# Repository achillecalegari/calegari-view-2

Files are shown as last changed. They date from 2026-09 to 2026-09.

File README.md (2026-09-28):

# Calegari View 2

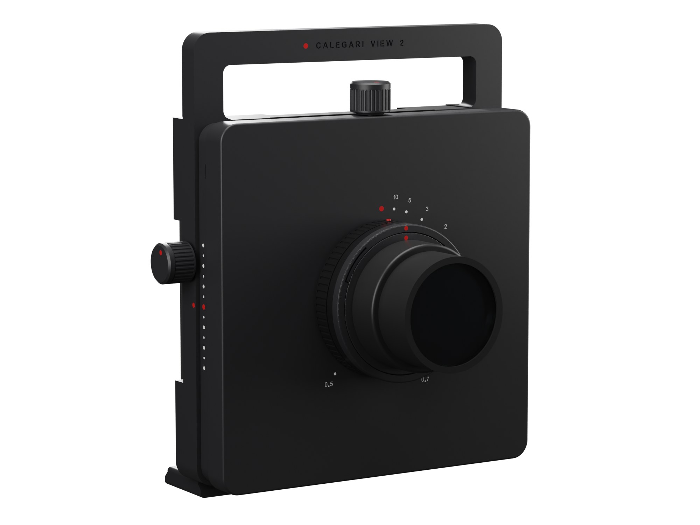
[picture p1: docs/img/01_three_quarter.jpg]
Calegari View 2


A rigid 6x7 view camera for architecture that you print at home and put together without a single screw. No inserts, nuts, springs, bushings or grub screws: the printed parts slide in dovetails, snap together and press in. The rise is a self-locking printed worm turned from a knob on the side through a printed miter pair, the shift knob rides on the lens panel, and the back turns from landscape to portrait with a click. Only the focusing helicoid and a sheet of velvet are bought, then the lens and the film back.

**[Project page](https://achillecalegari.github.io/calegari-view-2/)** · [Shopping list](docs/bom.md) · [Test prints](docs/test-prints.md) · [Printing](docs/printing.md) · [Assembly](docs/assembly.md) · [Calibration](docs/calibration.md) · [Using the camera](docs/using.md) · [Design notes](docs/design.md)

## Why

[Calegari View 1](https://github.com/achillecalegari/calegari-view-1) works, but building it means buying and sorting screws, inserts and nuts in half a dozen sizes. View 2 asks what a printer can do by itself. Every fastener of View 1 has a printed answer here: dovetail ways with a flexure beam instead of a gib, a self-locking worm and a rack and pinion instead of lead screws, knobs that snap onto their shafts, plugs that close the ways, a bayonet for the lens boards. It also moves further (30 mm each way instead of 25), the film turns instead of the camera, and it looks like one object: at zero the three plates are a single square block.

## What it is

| | |
|---|---|
| Format | 6x7 (56 x 69.5 mm), Mamiya RB67 Pro, Pro-S, Pro-SD backs on a Graflok-type seat (View 1's) |
| Lens | 65 mm large-format wide angle in Copal 0 (Super-Angulon, Nikkor-SW, Grandagon-N) on a 70 mm round board, one per lens |
| Movements | rise and fall 30 mm on a self-locking worm, pi mm per turn: it stays where you leave it, whatever the lens weighs; shift 30 mm each way on a rack and pinion, 37.7 mm per turn; a click at zero, hard stops at the ends |
| Back | turns 90 degrees on a round rotator, a click and a stop at landscape and at portrait; the camera stays level on the tripod |
| Clean corners | 30 mm on one axis, 25 + 25 mm combined at infinity, in both orientations; the lens's image circle is the limit, not the camera |
| Focus | M65 helicoid 17 to 31 mm, turned by its own grip; engraved distance scale from infinity to 0.5 m |
| Lens change | a three-lug bayonet, a 40 degree turn and a click; the shutter always ends upright |
| Tripod | the foot is an Arca-Swiss dovetail across the whole width, printed with the body |
| Handle | full width, posts and bar the same 16 mm, engraved name; the shift knob centred in its window |
| Light seal | self-adhesive velvet between the sliding plates, at least 6.1 mm wide at every position; a ring labyrinth behind the rotator |
| Size | 180 x 222 mm front (197 mm wide with the rise knob), 161 mm deep with back and lens |
| Weight | about 1 kg without back and lens, helicoid included (estimate from the model) |
| Bought | the helicoid and a sheet of velvet: 40 to 70 EUR, plus ASA and a little TPU |

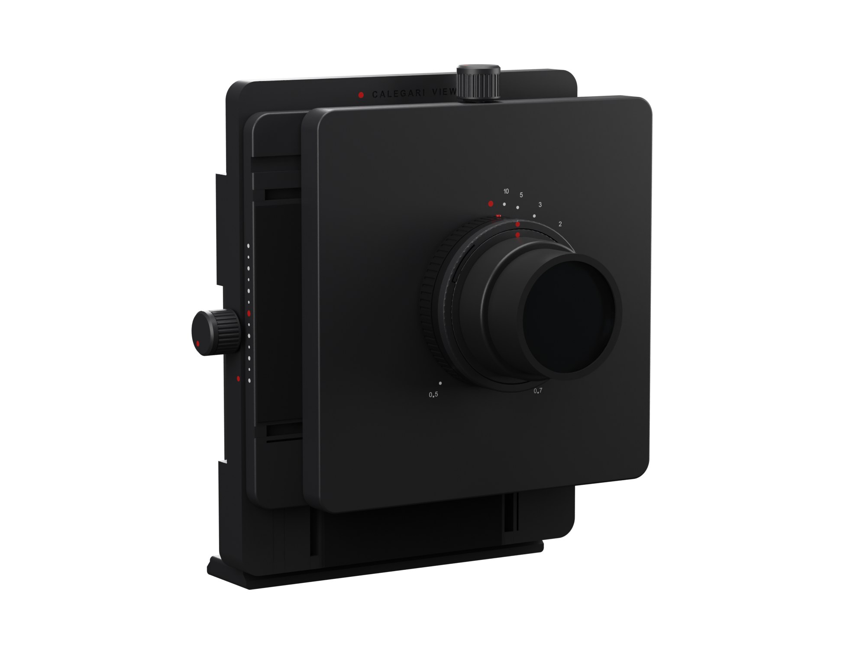
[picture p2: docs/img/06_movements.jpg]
Rise and shift


## How it works

| Function | How |
|---|---|
| Body | one print: body, full-width handle, the Arca foot, the rotator's recess with its lugs and springs |
| Ways | printed 60 degree dovetails; one groove of each pair has a flexure beam for a wall, which preloads the plate: no gib, no grubs, and it takes up wear by itself |
| Rise | a printed worm hidden in the body's right side; its rack is moulded into the Y plate as the exact negative of the worm. A 7 degree lead against a 17 degree friction angle: self-locking. A printed miter pair turns it from the knob in the middle of the right side face |
| Shift | module 1 rack and 12-tooth pinion, teeth printed in the bed plane; the pinion lives in the lens panel, its knob on the panel's top edge, so it rides with the lens |
| Knobs | knurled, snap onto a D-shaped shaft; a TPU wave washer under each gives an even drag |
| Zero clicks | a flat spring cut into the moving plate's back, with a bump that drops into a dimple |
| Stops | the grooves are closed at one end; a printed plug pressed into the other end after assembly |
| Focusing | the helicoid screws into an M65 thread printed in the lens panel. Infinity sits 0.3 mm short of its closed stop, like any lens |
| Lens mount | a ring flush with the helicoid, so helicoid and mount read as one barrel; the board's plateau is printed to the lens's flange focal distance |
| Back | View 1's Graflok seat on a round rotator: two lugs, three printed springs, a stop peg; a red blade in dovetail rails, clamped by a printed wheel on a printed M6 stud |

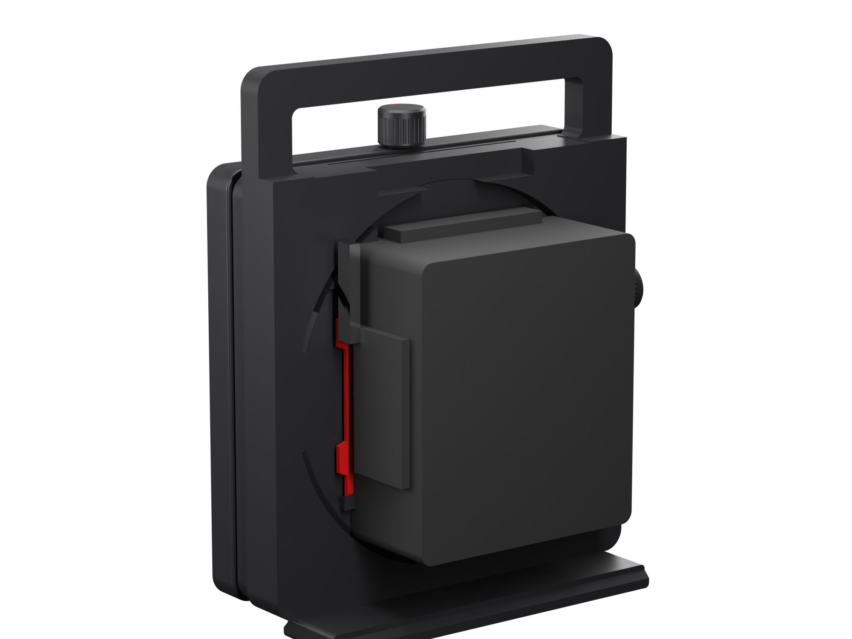
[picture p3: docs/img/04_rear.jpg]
From behind


## Checked before it is printed

- `cad/check.py`: every pair of parts at eleven positions: zero, the four corners of the travel, two single-axis ends, blade open, the back in portrait and half way round. Designed contacts (flexure preload, detent bumps, pressed rack, plugs and peg, squeezed washers) each have a volume budget; everything else must not touch. **0 problems.**
- `cad/fitcheck.py`: the mechanisms: the worm against its rack over the whole travel, the miter pair over a tooth pitch, every part going in and in order, the plugs and the collar, the rotator going in only at its angle, held on its lugs, stopped at both ends; the bayonet, the pinion, the knobs' snap, the Graflok blade, the dovetails, the test rigs. **62 checks, all pass.**
- `cad/seal_check.py`: the velvet band between the sliding plates, swept every 5 mm. **6.15 mm at the narrowest.**
- `cad/optics_check.py`: rays from the lens to the four corners of the film through every part, at infinity and focused close, landscape and portrait. **Clean at 30 mm on one axis and 25 + 25 combined at infinity; 22 + 22 at about 0.9 m.**

## Print, then build

1. [Test prints](docs/test-prints.md): four small plates that prove the thread, the bayonet, the drive and the dovetails on your printer.
2. [Printing](docs/printing.md): seven plates.
3. [Assembly](docs/assembly.md): eleven steps in 22 illustrated sub-steps, no tools but scissors and a craft knife for the velvet.
4. [Calibration](docs/calibration.md): the light test, infinity, other lenses, the feel of the movements.

Everything is generated with Python and [build123d](https://github.com/gumyr/build123d) from `cad/params.py`: change a number, run `python export.py`, print.

## Licence

[CC BY-NC-SA 4.0](LICENSE): build it, change it, share it with credit; do not sell it. The RB67 interface comes from View 1, measured from [Super-67](https://github.com/DamienHazard/Super-67) and the [RB67 pinhole body](https://www.thingiverse.com/thing:7270507).

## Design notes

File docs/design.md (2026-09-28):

# Design notes

[Back to the project](../README.md)

View 2 asks one question of [View 1](https://github.com/achillecalegari/calegari-view-1): which of its sixty-odd bought fasteners can a printer replace, and how, without the camera getting worse? All of them, it turned out. Then two more: can it look like one object instead of a stack of parts, and can the film turn instead of the camera?

## What replaced what

| View 1 | View 2 | How it prints |
|---|---|---|
| Printed rails screwed on with M2.5 and M3 into inserts | grooves cut into the body and the Y plate, tongues printed on the moving plates | grooves open on the bed, tongues on top, 30 degree flanks |
| Gib strip and three grub screws per way | one groove's outer wall is a flexure beam, 1.2 mm thick and 7 mm tall, 0.25 mm interference | the slit prints open on the bed; the beam bends across the layers |
| M6 lead screw, brass nut, bushings, cap nut (rise) | a printed worm, 8 mm pitch diameter, and a rack moulded into the Y plate, cut as the negative of the worm; a printed miter pair turns it from the side knob | the worm and the knob's gear stand up; the rack's layers each hold the worm's tooth profile |
| M6 lead screw and nut (shift) | module 1 rack and 12-tooth pinion, 37.7 mm per turn | teeth in the bed plane: exact involutes; the rack prints lying on its side |
| O-ring under the knob | a TPU wave washer under each knob: a 0.8 mm ring on three feet each side, squeezed 0.3 mm | flat |
| Ball plunger and dimple | a flat spring cut into the moving plate's back, with a bump near its free end, and a dimple in the other plate | the spring prints flat over a cavity |
| Knobs with a stud, a nut and a grub screw | knurled knobs that snap onto D shafts: two tabs drop into a groove | crown down; the tabs bend in the bed plane |
| Hard stops at the ends of the screw channels | closed groove ends, and a plug pressed into the open end after assembly | |
| RafCamera metal flange, four screws | an M65 x 1 thread printed in the lens panel | 0.12 mm layers, thread axis vertical |
| Focus ring with four grub screws and a hidden stop | the helicoid's own grip; a scale engraved on the panel, an index painted on the grip | |
| Technika board, holder, latch, spring, screws, inserts | a 70 mm round board on a three-lug bayonet with a flexure detent | the lugs' undersides are chamfered: no overhang |
| Brass shims for other lenses | the board's plateau is printed for each lens's flange focal distance | `python board.py 71.2` |
| Graflok module, four screws, four inserts; an L bracket for portrait | a round rotator that carries the Graflok seat and turns the back 90 degrees, held by two lugs and three printed springs | front face down; the lugs are 45 degree cones, no overhang |
| Graflok wheel on an M3 screw | a printed wheel on a printed M6 stud | stud printed standing |
| Two aluminium Arca plates, screws, inserts | the foot is an Arca dovetail, printed with the body | 45 degree flanks |
| Top handle, screws, inserts, levels | printed with the body, full width | |

What stayed bought: the helicoid, a precision thread that must not wobble or tilt the lens, and it costs less than the test prints of a printed one; and the velvet. TPU lip seals were drawn and dropped: no single lip stays on solid faces on both sides while two plates slide in two directions. The velvet seals by area, as on View 1.

## Why the front standard stays up

The front standard (Y plate, lens panel, helicoid and a 65 mm lens in its shutter) weighs about 0.8 kg: 8 N on the rise drive. The first View 2 raised it with a rack and a 12-tooth pinion, like the shift. A spur pinion runs backwards as easily as forwards: 8 N at its 6 mm pitch radius is 0.05 N·m trying to turn the knob, and nothing but the friction of the ways was holding it. With a light coat of PTFE, which the guide recommended, the front would have crept down on its own.

The rise is now a worm. One turn of the knob moves the plate one lead, pi mm, and the lead climbs the 8 mm worm at 7.1 degrees. A load on the rack pushes along the worm's axis, and it can only turn the worm if the flank's slope beats the friction on it: dry ASA on ASA has a friction angle of about 17 degrees, far above 7.1. The worm cannot be turned by its load, at any position, with any lens. PTFE would bring the friction angle near the lead angle, so the worm and its rack stay dry; the shift, which gravity does not pull while the camera is level, keeps its fast rack and pinion.

The rack is the other half of the trick. A straight-toothed rack only matches a worm in the plane through its axis; a millimetre to either side the worm's flank has moved and the teeth collide (the first prototype did, by 3 to 9 mm³). But a worm that turns is the same surface as a worm that slides along its axis, so the rack that meshes with it over its whole face is simply the negative of the worm: a slice of a nut, cut by a worm 0.15 mm fatter than the real one. In each printed layer of the Y plate the rack's section is the worm's own tooth profile. `fitcheck.py` turns the worm through the whole travel against it: 0.003 mm³ of contact, numerical noise.

The worm stands inside the body's right side and nothing of it shows. Its top carries a small straight bevel gear; a second one, on a shaft through the side face, meets it at right angles: a miter pair, 12 teeth, module 0.75, one to one. The knob sits on that shaft; turned clockwise, it raises the front standard. Both gears stay inside the worm's own envelope, 10.2 mm across, so the body stays 22 mm deep around them. Their teeth end on the back cone, as on a real bevel gear: the core behind each heel stays inside the other gear's reach, and every slope is 45 degrees or steeper, so both print standing without support. A collar pressed into the side bore under the knob holds the knob's gear in; the pin at the worm's bottom stands in a plug pressed into the bore from below, and that seat is the thrust bearing. A small stub on the knob's gear, just above the worm's top, stops the worm lifting.

The knob sits in the middle of the side face, the body and the handle's post together. It cannot come lower: the gear sits above the worm, the worm above the rack's highest point, and the rack's channel has to stay behind the Y plate at every rise and fall, so the rack has only three teeth and starts as low as that allows.

## The back turns, the camera does not

View 1 needed an L bracket and a second Arca plate for portrait, and a camera on its side is awkward to use. View 2 turns the film instead. The Graflok seat, its rails, blade and wheel are one round plate, the rotator, 160 mm across, in a round recess in the body's back.

- **Held:** two lugs at the recess rim, 45 degree cones on the underside, over a matching bevel on the rotator's back edge. Three flat springs cut into the recess floor push the rotator back onto them. The cone contact centres it and sets its plane; the film plane is the rotator's seat, and the ground glass and the film sit on the same seat, so focus stays true in both positions.
- **Clicks:** each spring's bump drops into a shallow dimple at landscape and at portrait. The dimples are 0.25 mm deep against a 0.4 mm bump, so the springs keep part of their preload at rest: the rotator never floats.
- **Stops:** a peg pressed through the body's left side face runs in a 90 degree groove on the rotator's rim.
- **Goes in:** the rotator has two notches in its rim. Turned 135 degrees, and only there, they pass the lugs. The working range, 0 to -90, never reaches that angle, and the peg, pressed in last, makes sure of it.
- **Dark:** the rotator's front face meets the recess floor across a ring rib that sits in a groove: light coming round the rim has to turn twice. The openings in front are square, so the frame fits in both orientations; that is one reason the block grew from 162 mm.
- **The dark slide:** it comes out on the photographer's right in landscape and at the top in portrait. The body is notched for it on both sides, and the handle stands 2 mm off the back so the slide's grip passes under it.

The springs sit at 15, 135 and 255 degrees. Three springs 120 degrees apart never meet each other's dimples inside the working range, so the back clicks only at its two positions; and none of the six dimples falls in the dark-slide relief, where the rotator is thin.

## One block

At zero the body, the Y plate and the lens panel are one square, 180 mm, with the Y plate 1.5 mm smaller all round: from the side the three layers read as a single block with two shadow lines. The body and the handle share one front face, printed in one piece, with the same 9 mm corner at the top of the handle and at the bottom of the body; seen from the front the handle's posts and its bar are the same 16 mm. The front of the camera is the lens panel and the barrel, nothing else: the helicoid's grip and the lens mount are the same diameter, so they read as one barrel, and the distance scale is engraved around it. There are two controls, two knurled knobs as on View 1: the shift knob stands on the lens panel's top edge, centred in the handle's window, and rides with the lens; the rise knob stands in the middle of the right side face.

Without the side leg the camera sits on the tripod one way, and it needs no plinth: the foot is simply an Arca-Swiss dovetail across the whole width, 9.5 mm tall, centred 32 mm behind the body's front face under the rotator. At full fall the plates drop past it in front of the clamp.

## Why 30 mm and not 40

With sliding plates, the light seal is geometry. The middle plate must stay covered by the plate behind it at the end of its travel, and its own window has to be wider than the light cone by the other plate's travel. Each millimetre of travel costs about 3.2 mm of camera. At 30 mm each way the light needs 170 mm; the block is 180, and the extra 5 mm a side is where the rise's miter pair lives. At 40 mm it would be over 200 and the body would no longer print in one piece on a 256 mm bed. And a 65 mm lens with a 160 mm image circle covers 30 mm on one axis anyway, 25 + 25 combined: past that, a bigger camera buys nothing.

## Focusing and infinity

The helicoid is closed at 17 mm; infinity is at 17.3. That is 0.3 mm, about 7 degrees of the grip, of travel past infinity, which every lens has and which makes infinity easy to find by feel. The lens panel's front sits at 70.5 - 5 - 17.3 = 48.2 mm from the film, the mount is 5 mm long, the board's front is at the lens's flange focal distance. Changing lens changes only the board.

## Findings along the way

- **The helicoid's rear tube limits combined shifts.** Its bore (61 mm) sits 5.5 mm deep in the lens panel. At infinity the corners stay clean to 25 + 25 mm; focused at about 0.9 m the lens moves out, the corner rays open up and the tube clips them past 22 + 22 mm. View 1's ray trace did not model the tube.
- **A detent bump must sit near the spring's free end.** Near the root, a 1.4 mm ASA spring deflected 0.4 mm would see several times its yield stress; near the free end, 12 MPa and a light 2 N click. The bump also has to reach across the gap, or it never clicks.
- **A solid TPU washer is a brick.** Squeezed 0.3 mm over its whole face it would push with hundreds of newtons. The wave washer bends between its feet: a few newtons, an even drag.
- **Press fits need interference.** The plugs, the rack and the stop peg are drawn 0.1 mm larger than their slots; with zero they would fall out.
- **A part has to be able to go in, and in the right order.** The worm's gear is wider than the rack lets through, so the worm goes up its bore before the Y plate, and its plug is notched where the rack's channel crosses the bore: the rack slides up past it and threads onto the worm from below. A second plug closes the channel afterwards. `fitcheck.py` checks every path.
- **A long press fit is a stuck part.** A plug pressed over 25 mm would need a vice. The long plugs press only over a 6 mm band at the bottom and slide above it.
- **A slot must stay inside its part.** With View 1's M3 screw the Graflok blade's slot was small; with a printed M8 stud it grew until it broke 0.2 mm through the blade's top edge, a hairline split. The stud is now M6 and 1 mm lower: 1.9 mm of blade above the slot, 3 mm below, checked in `fitcheck.py`.
- **A name prefix can hide a part.** An early ray trace skipped everything whose name began with "lens", including the lens panel. The panel is in the trace now.

## Checks

`check.py` (every pair of parts at eleven positions, landscape, portrait and half way; designed contacts on a volume budget), `fitcheck.py` (the mechanisms: worm and rack over the whole travel, the rotator going in, held and stopped, the miter pair, the parts going in, the bayonet, the pinion, the knobs, the Graflok blade, the dovetails), `seal_check.py` (the velvet band), `optics_check.py` (ray trace through every part, at infinity and focused close, in both orientations).

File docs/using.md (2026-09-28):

# Using the camera

[Back to the project](../README.md)

## From the bag to the negative

1. **Tripod.** Clamp the foot: it is an Arca-Swiss dovetail across the whole width. The camera goes on one way only; for portrait you turn the back, not the camera. Level it with the tripod head's level or a spirit level laid on the handle. For architecture the camera stays level; the movements do the framing.
2. **Landscape or portrait.** Grip the back and turn it a quarter turn until it clicks.
3. **Zero.** Turn both knobs until they click: the red dots on the side and on top line up with the red indexes. The lens is centred on the film.
4. **Compose.** Ground glass on, shutter open at full aperture, dark cloth. The rise knob is in the middle of the right side: clockwise, as you face it, raises the lens, 3.14 mm per turn; the lens stays exactly where you leave it, whatever it weighs. The shift knob stands on the lens panel's top edge and travels with it, 37.7 mm per turn. The dots are every 5 mm, the bigger ones every 10.
5. **Focus.** Turn the helicoid's grip, with a loupe on the ground glass. The index on the grip reads the distance on the scale engraved around it.
6. **Close the shutter**, set the aperture and speed, cock it.
7. **Swap the ground glass for the film back** (Graflok: wheel loose, blade down, back on, blade up, wheel tight). Pull the dark slide, shoot, slide back in.

## What the movements are for

- **Rise.** The camera stays level, so verticals stay vertical; the lens goes up until the top of the building is in the frame. With a 65 mm lens, 30 mm of rise lifts the top edge of the frame from 23 to 42 degrees above the horizon.
- **Fall.** The same, downward: a table, a floor, a view from a balcony.
- **Shift.** Sideways: a facade straight on while standing to one side of it, or a mirror or a window without your own reflection.
- **Together.** Up to 25 + 25 mm at infinity. Check the corners on the ground glass at the taking aperture: with a 160 mm image circle that is its edge.

## Changing the lens

Turn the board firmly anticlockwise (seen from the front) until it stops, about 40 degrees, and lift it out. The next board goes in turned the same way, pushed flat, then clockwise until it clicks: red dots together, shutter upright. Ten seconds, no tools. Every board is printed for its own lens, so infinity stays where it was.

## Care

- A light coat of dry PTFE on the dovetails and the shift rack once a year. Never on the rise worm or its rack: they must stay dry to lock. No oil or grease anywhere on the ASA.
- Keep it out of a hot car: ASA is fine to about 90 C, the velvet's glue is not.
- If a plate gets stiff after months, the flexure takes up the wear by itself; stiff means dirt: slide the plate out (pull the two plugs with a pin; for the Y plate, pull the rack plug too and turn the rise knob anticlockwise to run the rack down off the worm), wipe, back in.

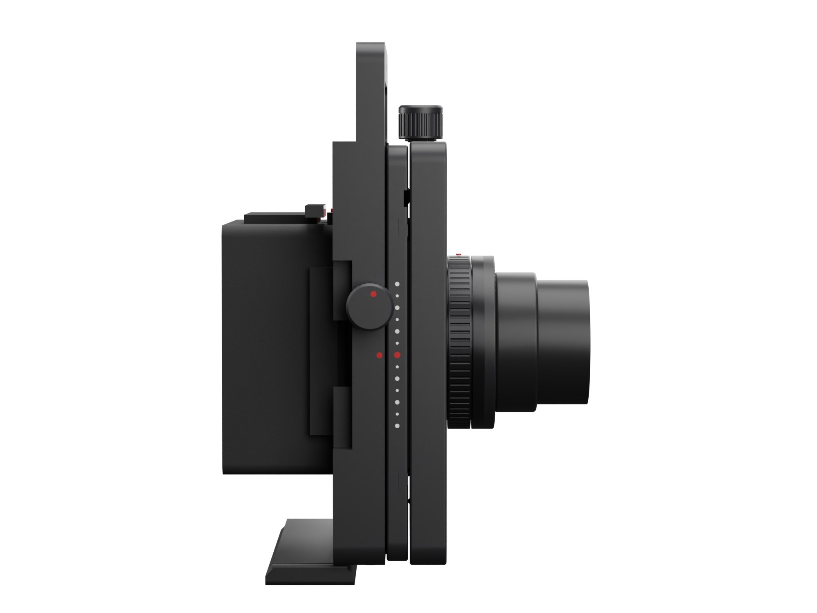
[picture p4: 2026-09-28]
docs/img/03_side.jpg

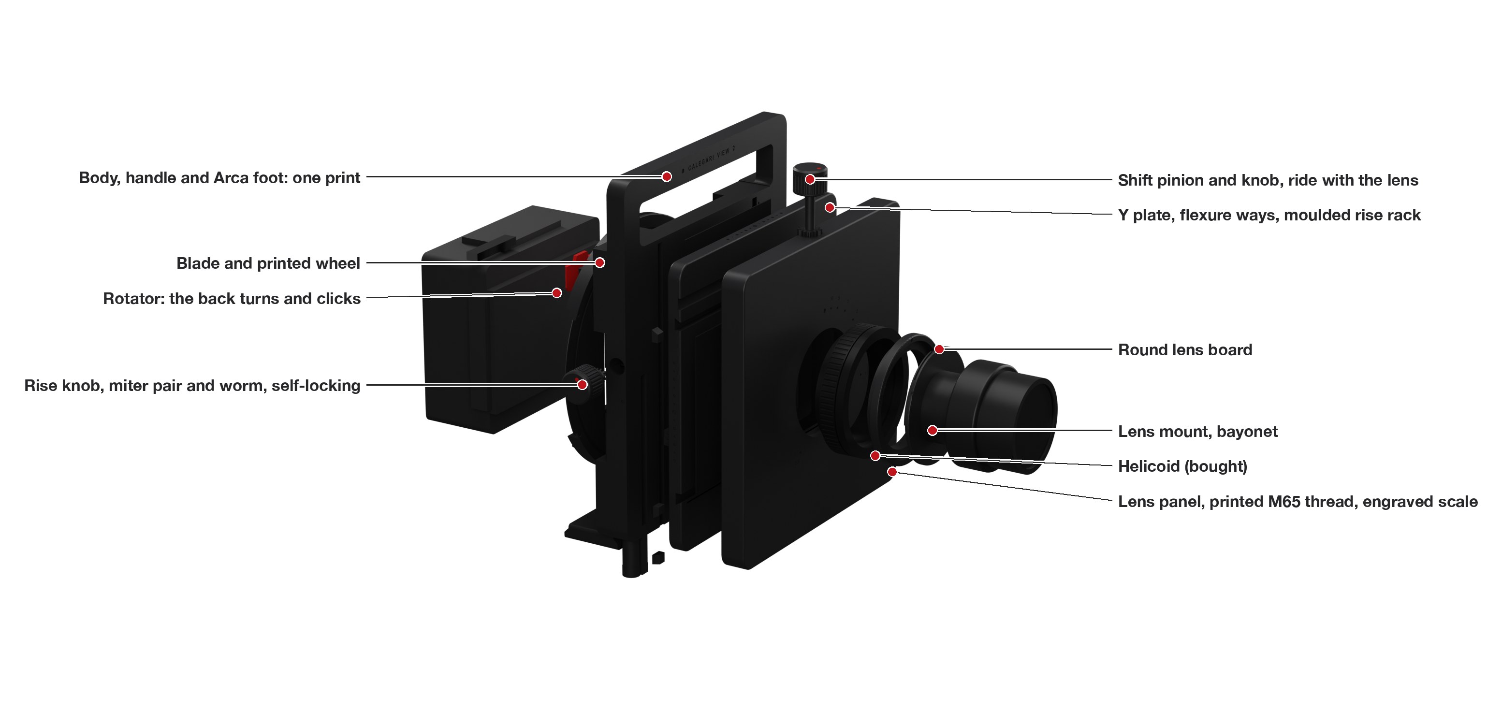
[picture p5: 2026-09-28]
docs/img/07_exploded.jpg

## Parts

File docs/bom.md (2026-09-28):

# Shopping list

[Back to the project](../README.md)

## The camera

| Item | Spec | Qty | Where | About |
|---|---|---|---|---|
| Focusing helicoid | M65 x 1 to M65 x 1, 17 to 31 mm; the front must not rotate | 1 | [AliExpress](https://it.aliexpress.com/item/1005007466119142.html) (option "m65-m65 17-31") or [RafCamera](https://raf.camera/products/m65x1-focusing-helicoid-with-17-31mm-extension-range) | 30 to 60 EUR |
| Velvet | black, self-adhesive, 0.9 to 1.2 mm thick, one A4 sheet is plenty | 1 | [Amazon.it](https://www.amazon.it/dp/B005FWUK44) | 10 EUR |
| ASA | black, about 900 g (a 1 kg spool); red, a few grams for the Graflok blade | 1 kg + a little | [Bambu Lab](https://eu.store.bambulab.com/products/asa-filament) | 30 EUR |
| TPU 95A | black, two grams for the two wave washers | a little | any | |
| Acrylic paint | red and white, a toothpick: the dots and the numbers are engraved to be filled | 1 each | any art shop | |
| Dry PTFE spray | optional: one light coat on the dovetails and the shift rack, never on the rise worm | 1 | any hardware shop | |

That is all. No screws, inserts, nuts, springs, bushings, grub screws, levels or Arca plates.

## To shoot with it

| Item | Spec | Where |
|---|---|---|
| Lens | 65 mm large-format wide angle in a Copal 0 shutter: Schneider Super-Angulon 65/8 or 65/5.6, Nikon Nikkor-SW 65/4, Rodenstock Grandagon-N 65/4.5. An image circle of 160 mm or more covers the full movements | used |
| Film back | Mamiya RB67 Pro, Pro-S or Pro-SD, 120 | used |
| Ground glass | a Graflok 23 ground glass back (Mercury Works makes new ones), or a used one | new or used |
| Cable release | any, for the shutter | |
| Dark cloth, 4x loupe | for the ground glass | |

Every lens gets its own printed board: [calibration](calibration.md) tells how to print one for a lens other than the Super-Angulon 65/8.

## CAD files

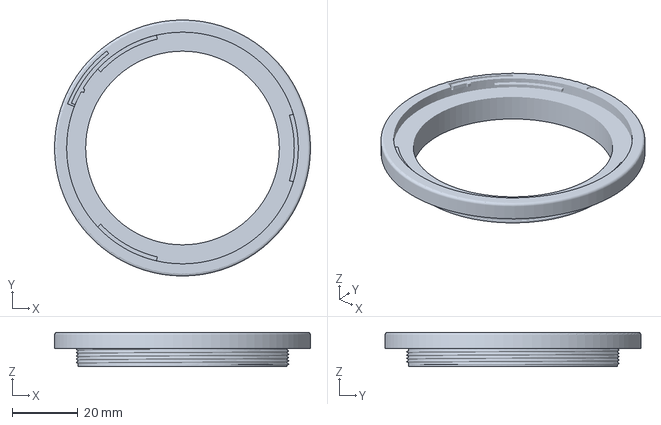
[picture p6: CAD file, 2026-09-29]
print/plates/plate_05_black_0.12mm_layers.3mf
78.0 x 78.0 x 10.5 mm

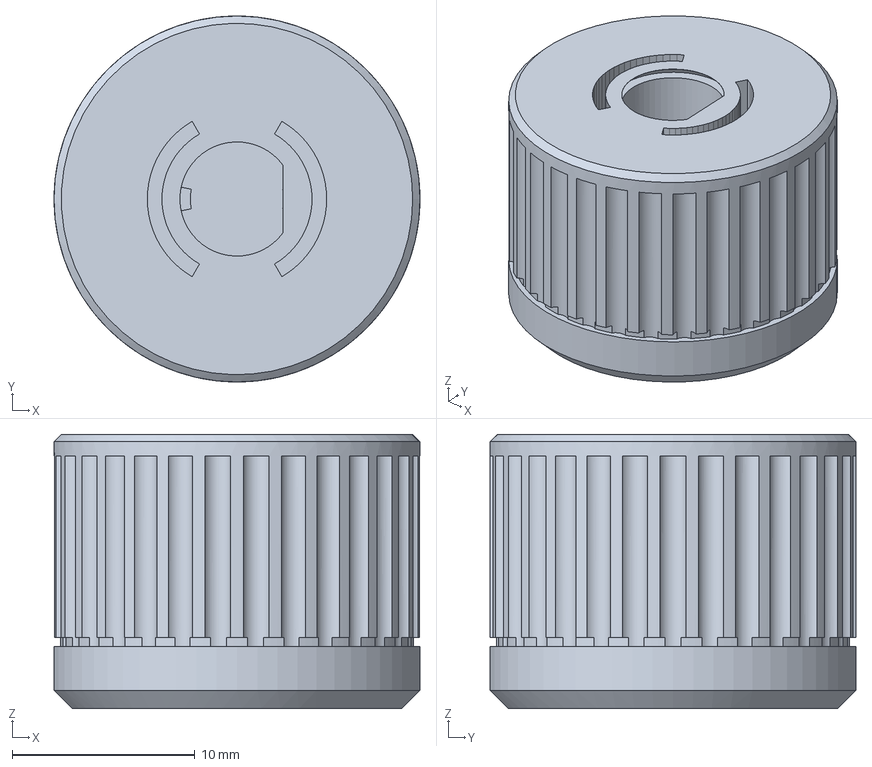
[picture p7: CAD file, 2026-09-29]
print/step/knob.step
20.0 x 20.0 x 15.0 mm

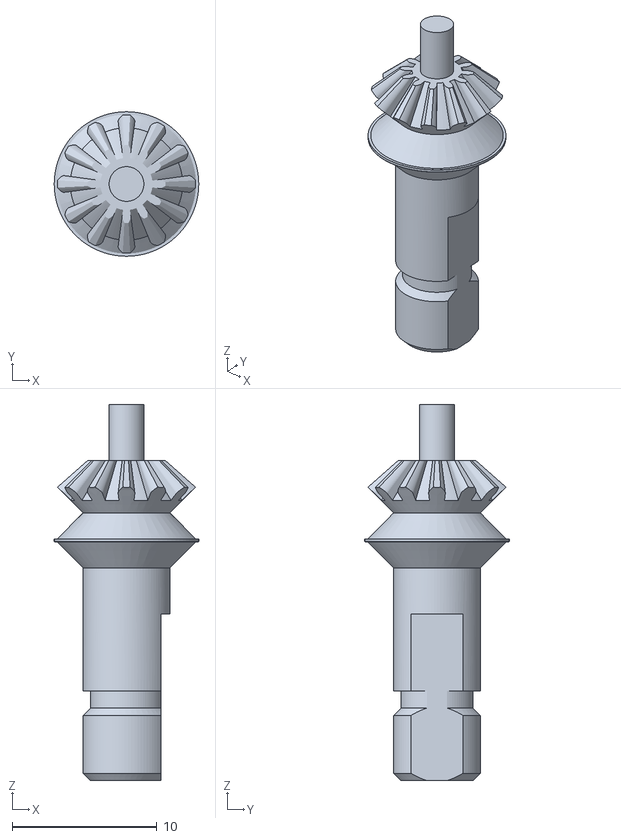
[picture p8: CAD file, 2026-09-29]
print/test/knob_gear.stl
10.0 x 10.0 x 26.0

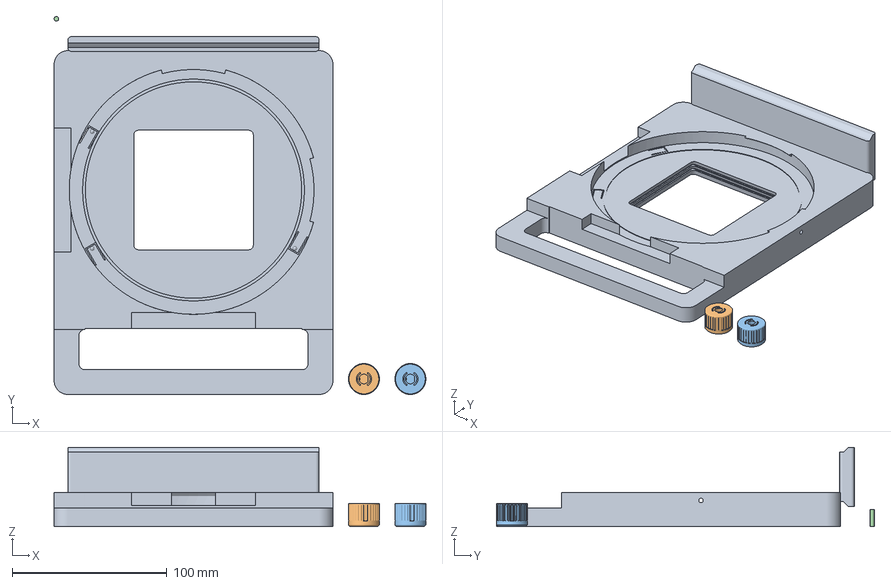
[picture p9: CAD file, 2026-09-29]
print/plates/plate_01_black.3mf
240.0 x 244.0 x 51.0 mm
knob_1
knob_2
stop_peg

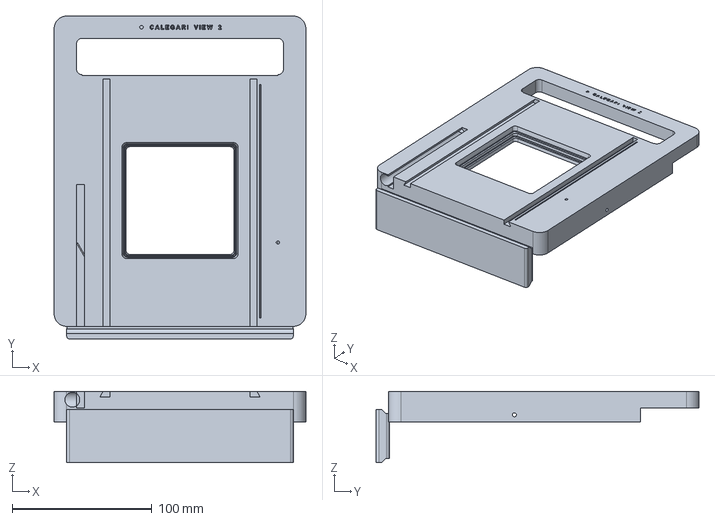
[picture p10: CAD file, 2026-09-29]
print/step/body.step
180.0 x 231.0 x 51.0 mm

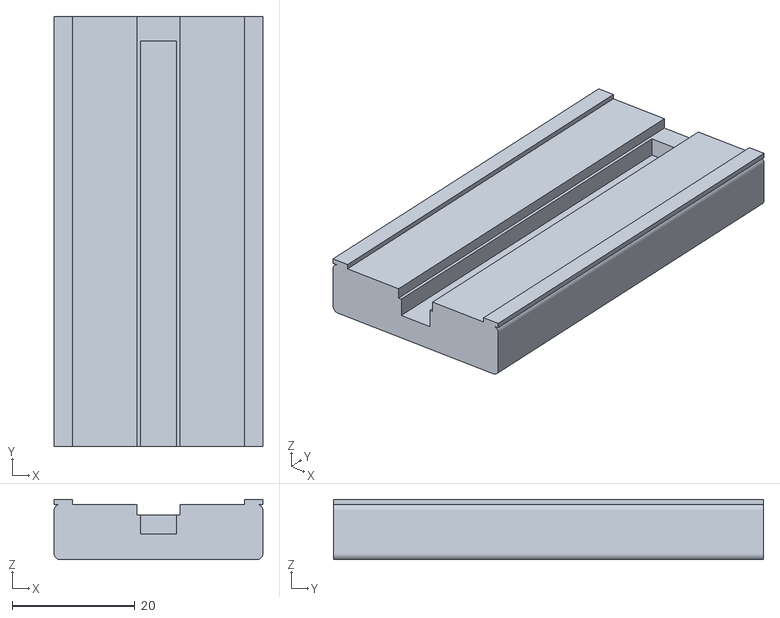
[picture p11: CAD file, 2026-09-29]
print/test/rack_carrier.stl
34.0 x 70.0 x 9.80

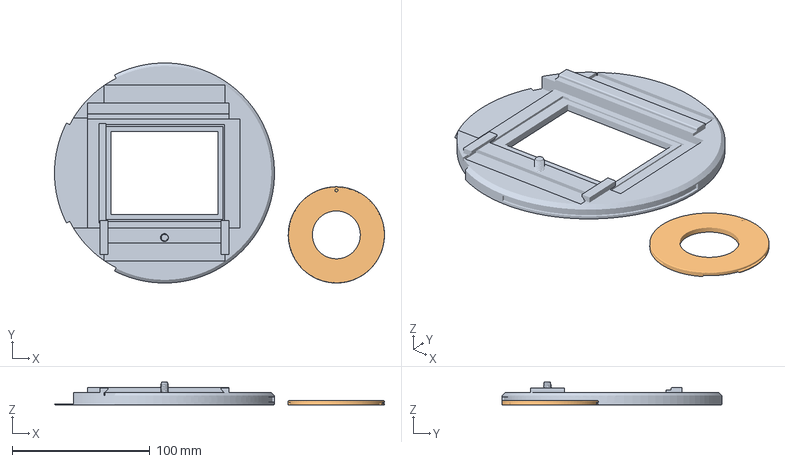
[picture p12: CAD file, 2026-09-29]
print/plates/plate_03_black.3mf
239.9 x 160.0 x 16.4 mm
rotator
lens_board

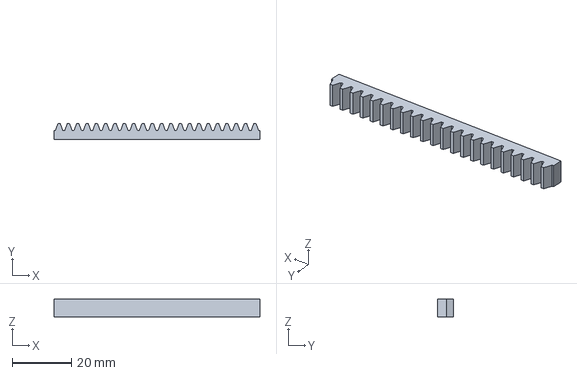
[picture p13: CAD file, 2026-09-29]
print/step/rack_shift.step
69.4 x 5.25 x 6.00 mm

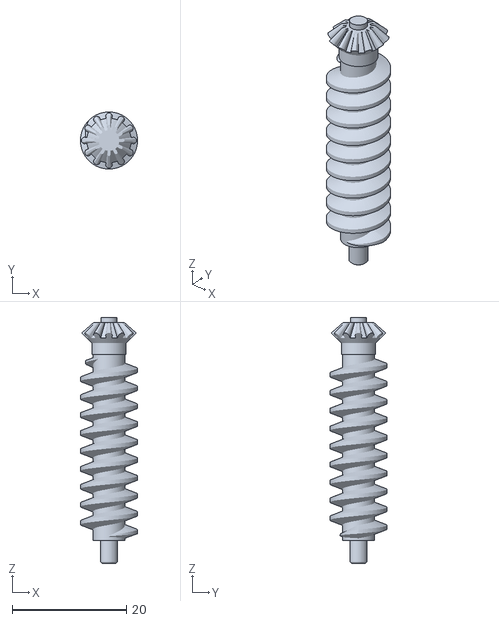
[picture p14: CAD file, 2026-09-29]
print/test/worm_short.stl
10.00 x 10.00 x 43.1

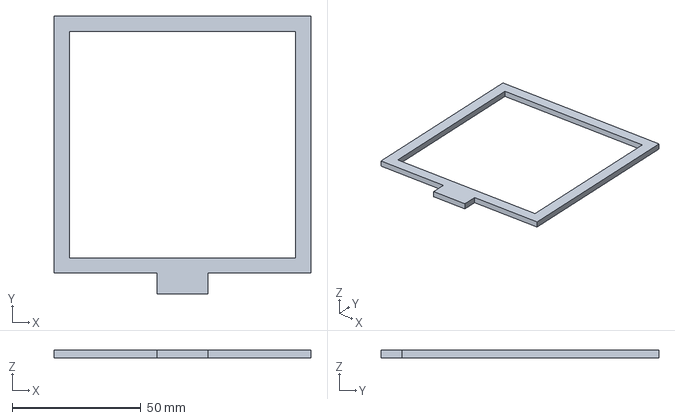
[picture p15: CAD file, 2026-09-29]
print/plates/plate_00a_shrink_gauge.3mf
100.0 x 108.0 x 3.00 mm

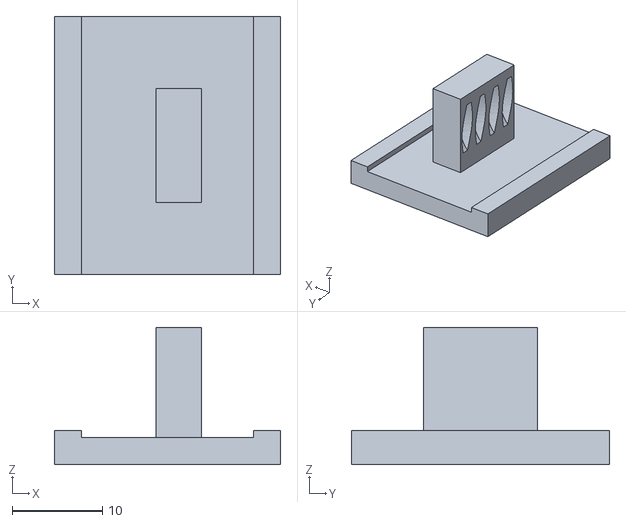
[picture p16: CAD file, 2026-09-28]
print/test/rise_rack_slice.stl
25.0 x 28.6 x 15.2

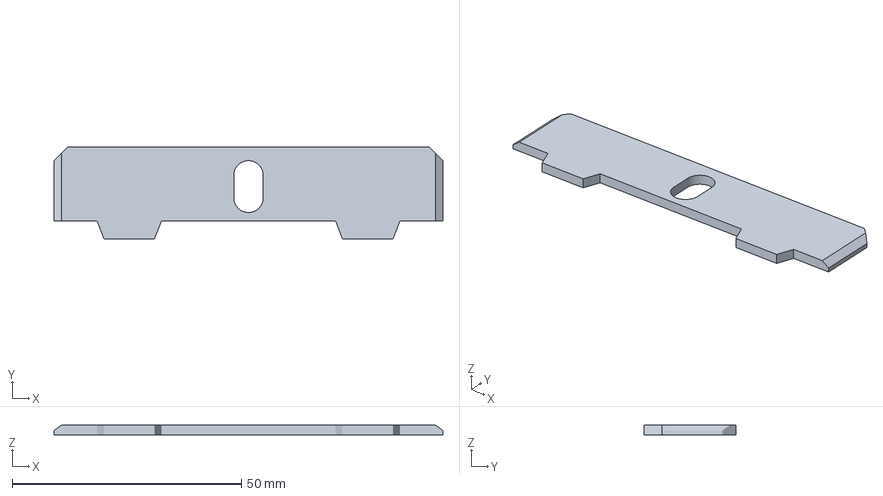
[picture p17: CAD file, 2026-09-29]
print/plates/plate_06_red.3mf
84.8 x 20.1 x 2.20 mm

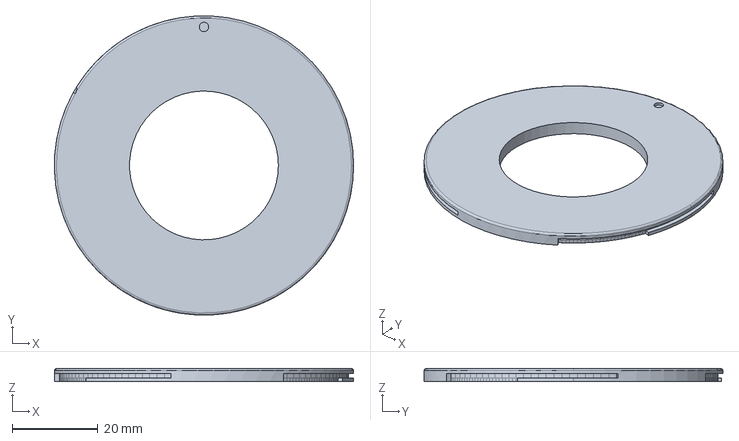
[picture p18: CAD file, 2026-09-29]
print/step/lens_board.step
70.0 x 69.9 x 3.00 mm

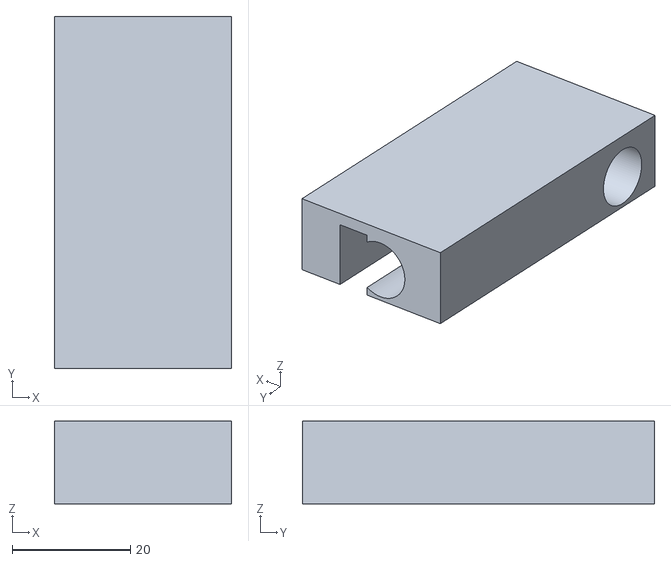
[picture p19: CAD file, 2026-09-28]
print/test/worm_block.stl
30.0 x 59.6 x 14.0

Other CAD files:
print/step/rise_knob_gear.step
print/plates/plate_00d_test_tpu.3mf
print/step/plug_x_bottom.step
print/test/worm_rig_plug.stl
print/plates/plate_00b_test_lens_drive.3mf
print/plates/plate_00c_test_ways_arca.3mf
print/plates/plate_02_black.3mf
print/plates/plate_04_black_0.12mm_layers.3mf
print/plates/plate_07_tpu.3mf
print/step/drag_washer.step
print/step/graflok_blade.step
print/step/graflok_wheel.step
print/step/lens_mount.step
print/step/lens_panel.step
print/step/pinion_shift.step
print/step/plug_rack.step
print/step/plug_worm.step
print/step/plug_x_top.step
print/step/plug_y_left.step
print/step/plug_y_right.step
print/step/rise_collar.step
print/step/rise_worm.step
print/step/rotator.step
print/step/stop_peg.step
print/step/y_plate.step
print/stl/body.stl
print/stl/drag_washer.stl
print/stl/graflok_blade.stl
print/stl/graflok_wheel.stl
print/stl/lens_board.stl
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

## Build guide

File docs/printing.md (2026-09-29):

# Printing

[Back to the project](../README.md)

Bambu Lab P1S (or any enclosed printer with a 256 mm bed), textured PEI plate, ASA. Set the shrinkage and pass the [test prints](test-prints.md) first.

| Plate | Parts | Notes |
|---|---|---|
| `plate_01_black` | body (with its handle and the Arca foot), two knobs, stop peg | the long one |
| `plate_02_black` | Y plate (with the rise rack), shift rack, Graflok wheel, the rise collar, six plugs | |
| `plate_03_black` | rotator, lens board | |
| `plate_04_black_0.12mm_layers` | lens panel, shift pinion, rise worm, rise knob's gear | 0.12 mm layers: the M65 thread, the gear teeth, the worm's thread, the miter pair |
| `plate_05_black_0.12mm_layers` | lens mount | 0.12 mm layers: the M65 thread |
| `plate_06_red` | Graflok blade | |
| `plate_07_tpu` | two wave washers | TPU 95A, external spool |

Every part is already oriented. The rule behind the orientations: whatever touches the bed is a face, a groove, a recess or an engraving, never a boss; tongues, bumps and rails are on top. The body, the Y plate, the lens panel and the rotator print front face down, so the engraved name, the distance scale and the grooves come out crisp on the textured plate. Gear teeth and racks lie in the bed plane, where the printer is most precise; the rise worm stands up, so its thread is drawn layer by layer like a screw, and the Y plate's rise rack is cut in the plate so each layer holds the worm's exact tooth profile. The worm and the rise knob's gear stand up too: their miter gears end in 45 degree back cones, so nothing overhangs. The knobs print crown down. The flexures (the ways' beams, the zero-click springs, the rotator's springs, the knobs' tabs) bend across flat layers, never by pulling layers apart.

| Setting | Value |
|---|---|
| Layers | 0.16 mm; 0.12 mm on the two plates that say so |
| Walls | 5 on the body, Y plate, lens panel and rotator; 4 elsewhere |
| Infill | 30 % gyroid; 100 % for the worm, the knob's gear, the pinion, the rack, the knobs, the collar, the board, the mount, the plugs and the peg |
| Supports | none, except the lens mount: its ring stands 6.5 mm out over the stub, so paint supports under the ring (tree, on build plate only); sand the ring's back flat where they touched, it seats on the helicoid |
| Brim | ears on the body, Y plate, lens panel and rotator corners; a 5 mm brim around the worm (84 mm tall, 10 wide), the rise knob's gear and the two long plugs |

The wave washers bridge over their own three feet (half a millimetre, 8 mm spans): no supports, a little sag does no harm.

## After printing

1. Pull any stringing out of the pockets and bores.
2. Slide a fingernail along the flexure slits (the thin slots beside two of the grooves) and under the three springs in the rotator's recess: they must be free for their whole length.
3. Fill the dots and the distance numbers: a drop of red or white acrylic with a toothpick, wait a minute, wipe across with a damp cloth. Red for the zeros, infinity and the indexes, white for the rest. The name stays black.
4. The red index on the helicoid's grip is painted at the end of the assembly, at infinity.

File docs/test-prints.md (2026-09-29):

# Test prints

[Back to the project](../README.md)

Print these before anything else. They are the real mechanisms of View 2, or exact slices of them: a few hours of printing tell you whether the camera will work on your printer, before the body takes a day.

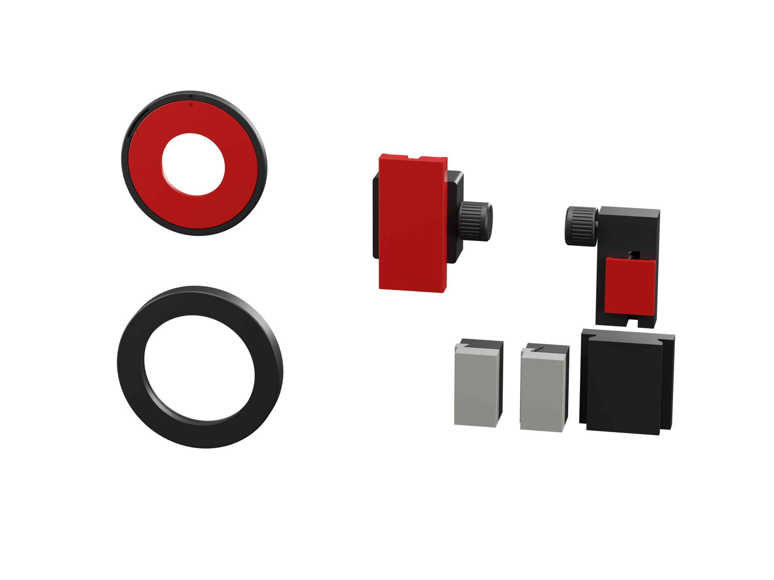
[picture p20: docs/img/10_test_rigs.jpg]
The test rigs, assembled


| Plate | Material | What |
|---|---|---|
| `plate_00a_shrink_gauge` | ASA | a 100 mm square frame: set the filament shrinkage first |
| `plate_00b_test_lens_drive` | ASA | M65 thread ring, lens mount, lens board; the shift rig (pinion with its shaft, knob, rack, pinion block, rack carrier); the rise rig (the top of the body's right side as a block, a short worm, the knob's gear, the collar, a knob, the plug, a rack slice) |
| `plate_00c_test_ways_arca` | ASA | dovetail grooves and tongues (rigid and flexure), a slice of the Arca dovetail |
| `plate_00d_test_tpu` | TPU 95A | two wave washers (external spool, not the AMS) |

Settings as for the camera ([printing](printing.md)), supports under the lens mount's ring only: 0.12 mm layers for the thread ring, the mount, the pinion, the worm and the knob's gear, 0.16 mm for the rest, 100 % infill for the small parts.

## Shrinkage first

Print the gauge, let it cool for ten minutes and measure the outside of the frame with a caliper, on both axes. If it is not 100.0 mm, set the shrinkage in the slicer (Bambu Studio: filament settings, *Shrinkage*, the measured value in percent) and print it again. Every part of the camera is drawn to size; a filament that shrinks 0.5 % turns a sliding fit into a stuck one.

## What to check

| Test | How | Good | If not |
|---|---|---|---|
| M65 thread | screw your helicoid's rear thread into the ring | by hand, no wobble, it seats flat | tight: raise `M65_FIT` by 0.1; loose: lower it |
| Focus direction | helicoid in the ring, look at it from the front and turn the grip toward close focus (the front comes out) | note which way it turns | clockwise: leave `FOCUS_DIR = 1`; anticlockwise: set `FOCUS_DIR = -1` before you print the lens panel, or the distance scale runs the wrong way |
| Mount | screw the mount into the helicoid's front | by hand, it seats flat | tune the stub in `mech.mount` |
| Bayonet | board in, turned 40 degrees back, then turn it to the stop | a click at the stop, no rattle, it comes out with a firm turn back | loose: `LUG_IN` +0.1; stiff click: the detent bump in `mech.mount` |
| Knob | shaft through the block, a wave washer over it, push the knob on | it snaps home and turns with an even, light drag | too free: `KNOB_OFF` -0.1; too stiff: +0.1 |
| Rise drive | the knob's gear into the block's side hole, the collar, a washer and a knob, as in [assembly](assembly.md) step 1; the worm up its bore from below, turning the knob as its gear meets the other, the plug under it, notch toward the channel; slide the rack slice up the channel from below, its rails on the block's face, and turn the knob as it meets the worm | the knob turns the worm with no scraping and draws the rack along, smooth, pi mm per turn; let go with a hand pushing on the slice: nothing moves | stiff: check the shrinkage; `WORM_BL` +0.05 (worm), `BEVEL_X` -0.1 (the two gears). It must never turn backwards under load: if it does, the worm or the rack is greasy, clean them |
| Rack and pinion | press the rack into the carrier's slot, teeth out; lay the carrier on the block, its two rails on the face; turn the knob | smooth, no skipped teeth, 37.7 mm per turn | rough: check the shrinkage first |
| Dovetails, rigid | slide the tongue in the plain groove | a light, even drag and no rocking | tight: `WAY_C_RIGID` +0.05 |
| Dovetails, flexure | the same in the slotted groove | a firm drag and no play at all, never binding | too firm: `WAY_INTERF` -0.05; play: +0.05 |
| Arca | clamp the coupon in your tripod head, tight | it holds and does not creep after a night | tell me: the fallback is a bought plate |

Every value above is in `cad/params.py` (or at the top of `cad/mech.py`). Change it and run `python testplate.py` again; when all pass, run `python export.py` for the camera.

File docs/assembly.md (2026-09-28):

# Assembly

[Back to the project](../README.md)

This guide assumes you have never built a camera. Each step is split into short sub-steps; every picture shows what is already built in place and only the parts of that sub-step pulled out along the way they go in, with a dashed line to where they go. The red letters match the table under the picture. Follow the steps in order: some parts cannot be reached later.

There is no screw in the camera. Parts slide in dovetails, snap onto shafts, press into slots, and one worm threads into its rack. The two controls are knurled knobs: the rise one on the photographer's right side, the shift one on the lens panel's top edge. Allow two hours for the first build.

## Words used in this guide

- **Front** is the lens side, **rear** is the film side.
- **Photographer's left and right** are as you stand behind the camera looking at the ground glass. A picture taken from the front shows them mirrored: the photographer's right is on the left of the picture.
- The **Y plate** moves up and down (rise and fall). The **lens panel** moves left and right (shift) and carries the lens. The **rotator** is the round plate at the back that carries the film back and turns it from landscape to portrait.
- A **dovetail way** is a groove with a slanted outer wall and a tongue that slides in it. In each pair, one groove has a thin slot beside its wall: that wall is a **flexure**, a spring that presses the tongue and takes out the play.
- The **worm** is the vertical screw inside the body's right side that raises the Y plate. Its **rack** is the row of teeth moulded into the back of the Y plate. The rise knob turns the worm through two small bevel gears, a **miter pair**: one on the worm's top, one on the knob's shaft.
- **Proud** means sticking out above a surface; **flush** means level with it.

## Before you start

1. **Print and check the parts**: everything in [printing](printing.md), including *After printing*.
2. **Pass the test prints**: [test prints](test-prints.md) tells you whether the thread, the bayonet, the worm, the pinion and the dovetails work on your printer. Do not assemble before they pass.
3. **Clean every slot, bore and pocket** of stringing. A hair of plastic in a dovetail feels like a gritty way forever.
4. **Keep the worm dry.** No grease, no oil, no PTFE on the worm or its rack: the dry friction is what holds the front standard (see [design notes](design.md)). The dovetails and the shift rack may get one light coat of dry PTFE.

### Tools

| Tool | Used for |
|---|---|
| Sharp scissors, a new craft blade, a steel ruler | the velvet |
| A flat piece of hard wood, about 60 x 30 mm | pressing the racks and plugs |
| A small clamp or a vice (optional) | the same, if your thumbs are tired |
| A toothpick, red and white acrylic, a damp cloth | the dots and the infinity index |
| Isopropyl alcohol, cotton buds | degreasing before the velvet |

### Four techniques you will use

**1. Pressing.** The racks, the plugs, the collar and the stop peg are drawn 0.1 mm larger than their slots: they stay by friction alone. Start the part square in its slot, lay the wood on it and press with your thumb or the clamp until it is flush. Never a hammer: ASA cracks. If a part will not go, look at the slot for stringing before you push harder.

**2. Snapping a knob.** Each shaft ends in a D flat and a groove. Turn the knob until its D bore lines up with the flat and push it on: two tabs inside the knob spread and drop into the groove with a click. To take a knob off, pull it straight off while rocking it slightly.

**3. Velvet.** Light is kept out by sliding faces 0.8 mm apart with self-adhesive velvet between them. There are two pieces, V1 on the body and V2 on the Y plate.

1. Print the templates in `print/templates/` at 100 %. Measure the 100 mm bar on the sheet: if it is not 100 mm, fix the printer scaling first.
2. Tape the template on the back of the velvet (the paper side), cut the outline with scissors and the window with the blade against the ruler.
3. Measure the velvet with a caliper, pressing lightly: 0.9 to 1.2 mm.
4. Degrease the plastic with alcohol. Peel off the backing, align one edge and lay the velvet down from that edge like a screen protector. Press it all over with your thumb.

**4. Threading the worm.** The rack meets the worm the way a nut meets a screw: it will not slide on, it has to be turned on. When the rack touches the worm, turn the rise knob slowly clockwise while you push the plate gently: the first tooth finds the thread within a turn and the knob then draws the plate up by itself.

---

## 1. Body and rise knob

**You need:** the body, the rise knob's gear, the collar, a wave washer, a knob.

### 1a. Check the body

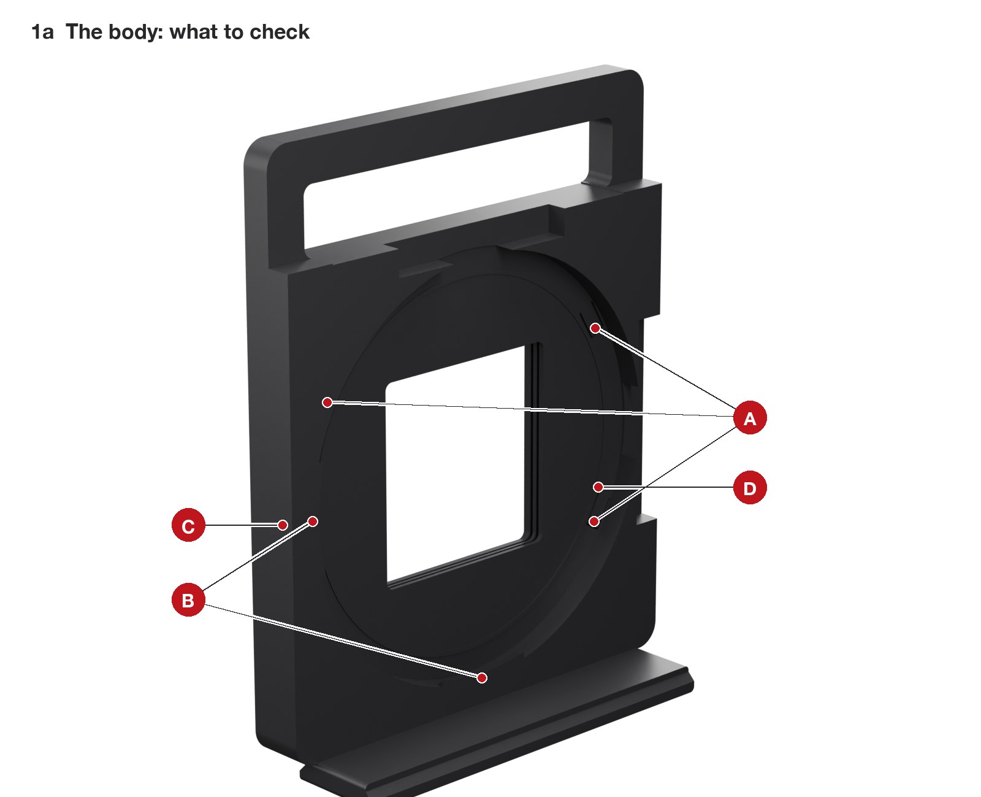
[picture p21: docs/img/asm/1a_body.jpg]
1a


| | What | Check |
|---|---|---|
| A | Three springs in the floor of the round recess at the back | Press each one with a fingernail: it moves and comes back. The small bump on each must be clean. |
| B | Two lugs at the rim of the recess | No stringing under them: the rotator's edge slides there. |
| C | The stop peg's hole, on the photographer's left side | Open, round, clean. |
| D | The ring rib in the recess floor | Whole all the way round: it is the light trap between the rotator and the body. |

Also run a fingernail along the slit beside the groove on the photographer's left: it must be open for its whole length. Look up the worm's bore from the bottom face with a torch: clean all the way to the side bore.

### 1b. The knob's gear and the collar

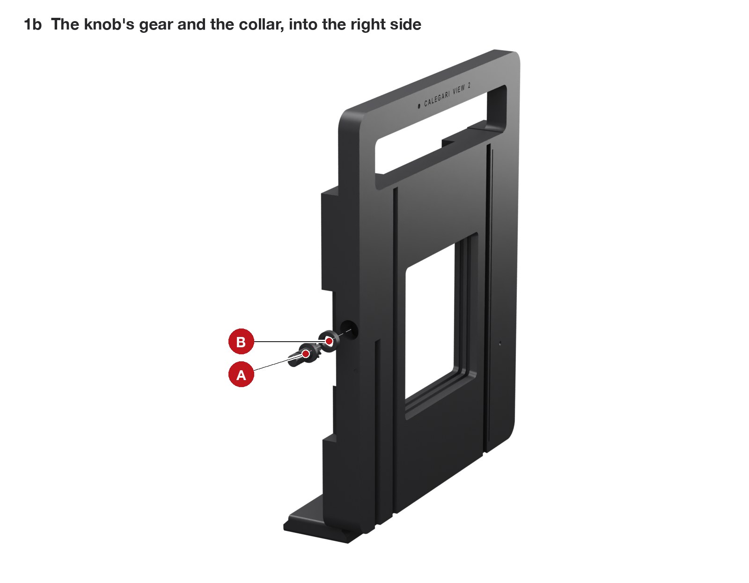
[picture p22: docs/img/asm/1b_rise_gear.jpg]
1b


| | Part | What to do |
|---|---|---|
| A | Knob's gear | Gear first, push it into the round hole in the photographer's right side face, until it stops against nothing: it sits free, its shaft sticking out. |
| B | Collar | Over the shaft and into the hole, flush with the side face (technique 1). It keeps the gear in; the gear turns freely behind it. |

### 1c. Washer and rise knob

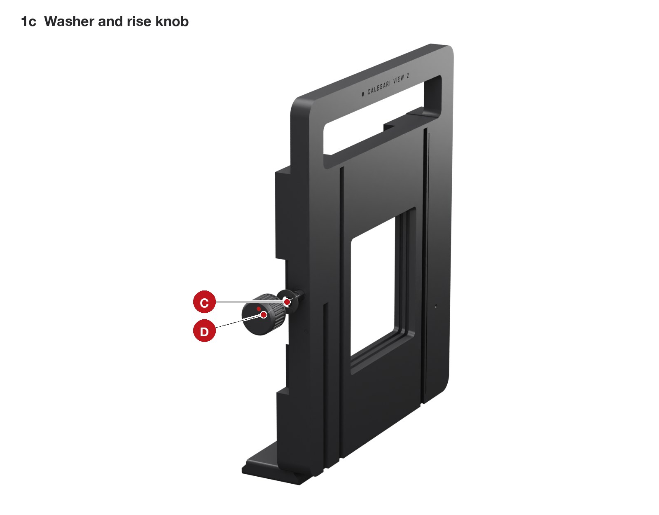
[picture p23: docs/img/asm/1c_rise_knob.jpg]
1c


| | Part | What to do |
|---|---|---|
| C | Wave washer | Over the shaft, against the collar. |
| D | Knob | Onto the shaft, flat to flat, until it clicks (technique 2). |

The knob turns with a light, even drag and nothing else: the worm is not in yet.

---

## 2. The rotating back

**You need:** the rotator, the stop peg, the red Graflok blade, the Graflok wheel.

### 2a. The rotator goes in

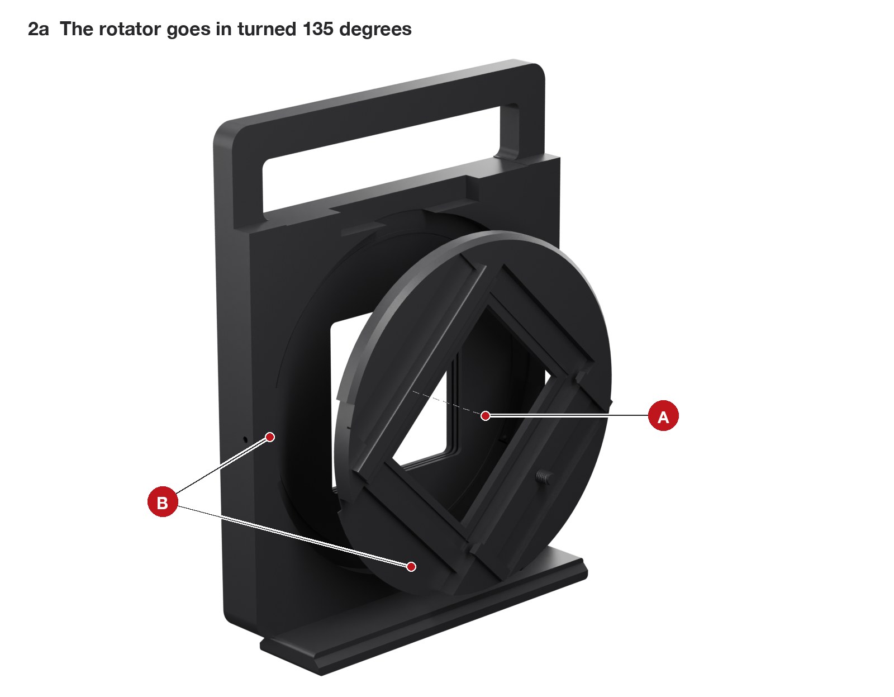
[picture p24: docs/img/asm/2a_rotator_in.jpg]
2a


| | Part | What to do |
|---|---|---|
| A | Rotator | Seat face (the side with the rails) toward you, the flat face toward the body. Its rim has two notches: turn it until they sit on the two lugs (B), push it into the recess against the three springs, and turn it anticlockwise as you look at it until it clicks. The blade rails are then at the top: landscape. |
| B | Lugs | The rotator's bevelled edge now runs under them; the springs press it back onto them. |

### 2b. The stop peg

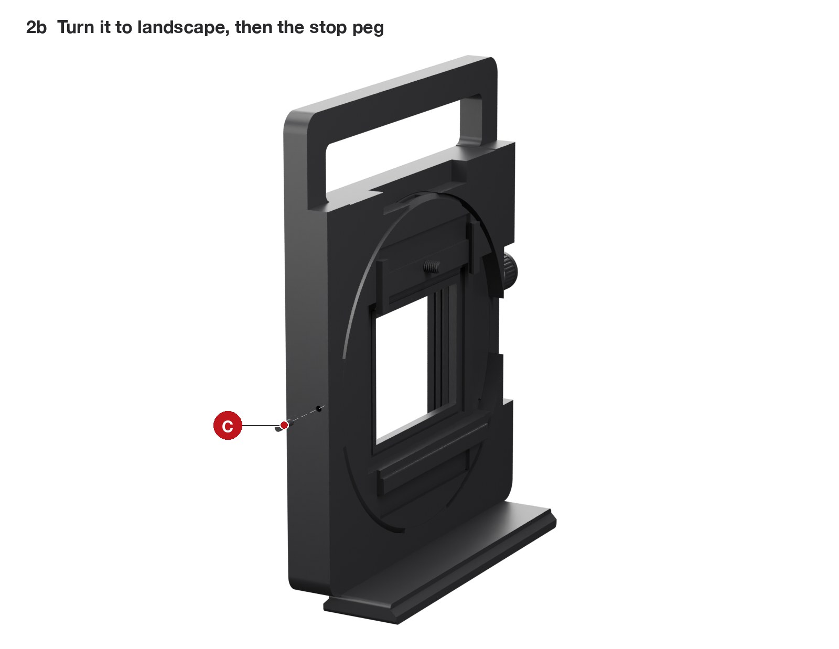
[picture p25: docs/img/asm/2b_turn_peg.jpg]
2b


| | Part | What to do |
|---|---|---|
| C | Stop peg | Press it into the hole in the photographer's left side face, flush (technique 1). |

Now grip the rotator's rails and turn it: a quarter turn anticlockwise (seen from behind) to portrait, where it clicks and stops, and back to landscape, where it clicks and stops again. It can no longer reach the angle where it came in.

### 2c. Blade and wheel

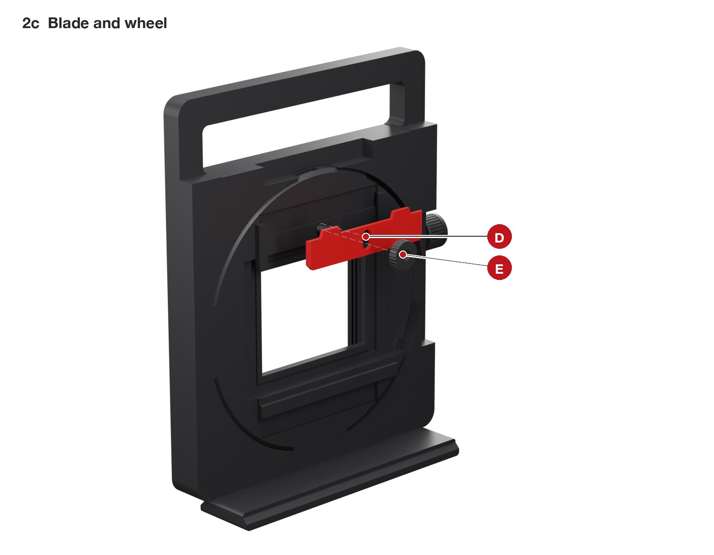
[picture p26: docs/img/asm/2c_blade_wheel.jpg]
2c


| | Part | What to do |
|---|---|---|
| D | Red blade | Slide it into the two rails on the rotator's back, from the top, its two tongues up. |
| E | Wheel | Screw it onto the printed stud through the blade's slot. Wheel loose: the blade slides; wheel tight: it is clamped. |

---

## 3. Velvet V1 on the body

**You need:** velvet V1, cut from `velvet_V1_body.svg`.

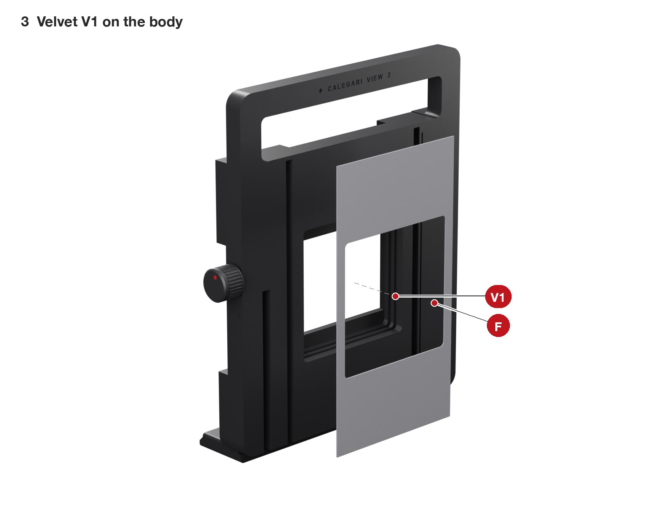
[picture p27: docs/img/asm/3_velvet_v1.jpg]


| | Part | What to do |
|---|---|---|
| V1 | Velvet | On the body's front face between the two grooves, window over the window, from the top edge to the bottom edge. It must not cover the grooves, the rack's channel on the photographer's right, or the zero-click dimple (F). |

---

## 4. The Y plate on the bench

**You need:** the Y plate, the shift rack, velvet V2.

### 4a. Check its back

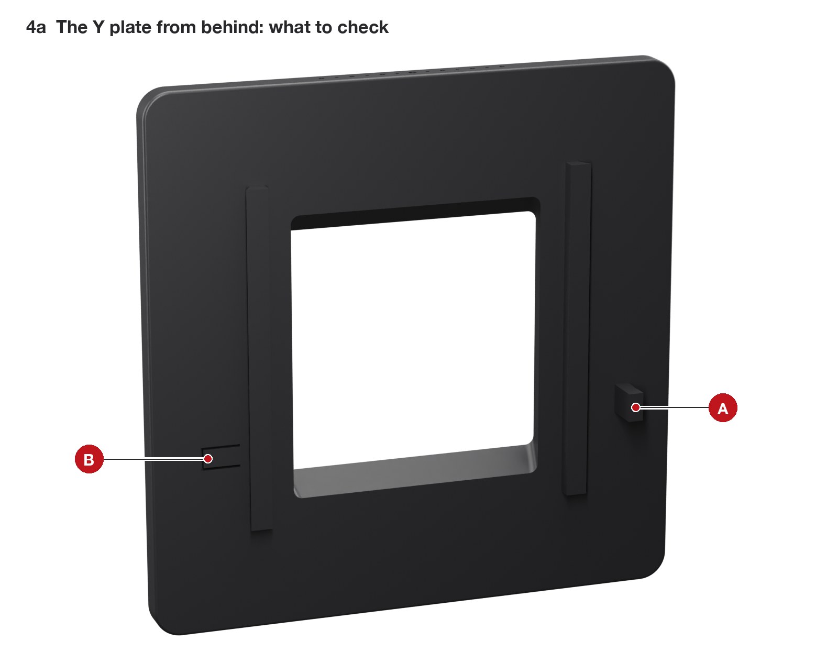
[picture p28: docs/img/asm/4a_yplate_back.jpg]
4a


| | What | Check |
|---|---|---|
| A | The rise rack, part of the plate | Four clean teeth, no stringing between them. Do not lubricate them. |
| B | The zero-click spring | It moves when you press it with a fingernail; its bump is clean. |

### 4b. Shift rack

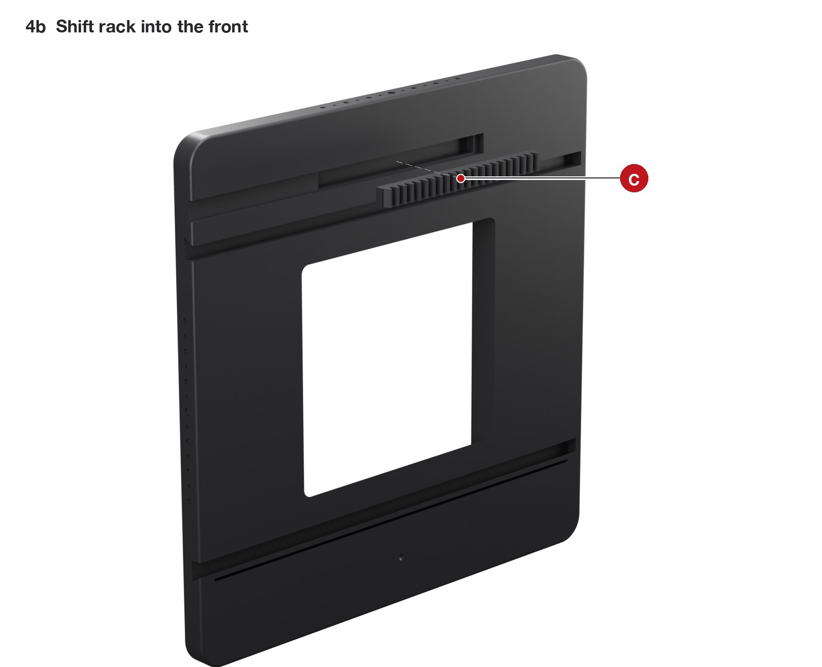
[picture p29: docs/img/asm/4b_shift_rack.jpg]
4b


| | Part | What to do |
|---|---|---|
| C | Shift rack | Press it into the slot at the top of the plate's front, teeth out, flush (technique 1). |

### 4c. Velvet V2

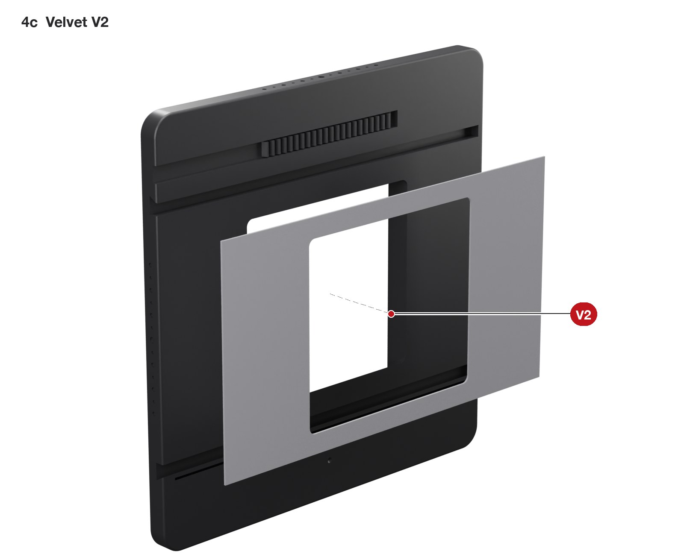
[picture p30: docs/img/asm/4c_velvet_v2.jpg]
4c


| | Part | What to do |
|---|---|---|
| V2 | Velvet | Template `velvet_V2_y_plate.svg`, on the front between the two grooves. The shift rack and the channel above it stay clear. |

---

## 5. The rise worm and the Y plate

**You need:** the rise worm, the worm plug, the Y plate as built in step 4, two plugs Y, the rack plug.

### 5a. The worm, up from below

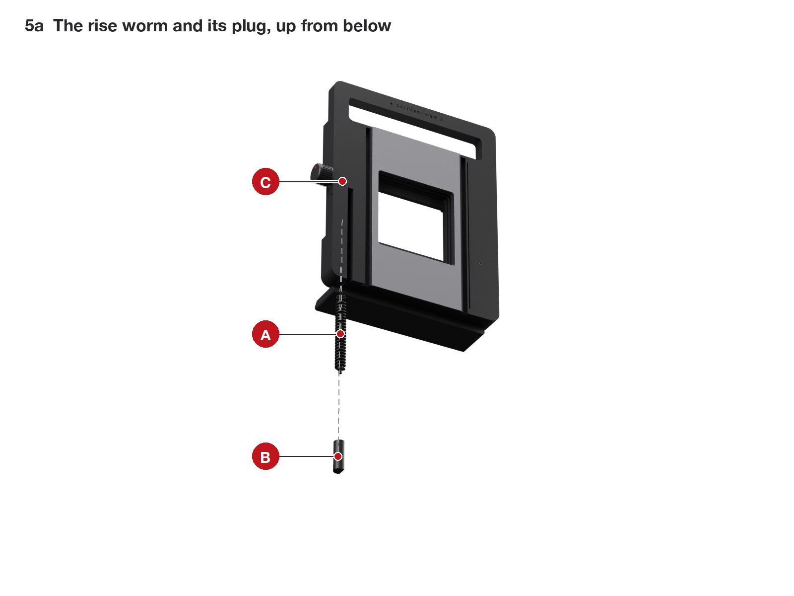
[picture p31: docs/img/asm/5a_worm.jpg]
5a


| | Part | What to do |
|---|---|---|
| A | Rise worm | Camera on its back, bottom face toward you. Gear first, push the worm up its bore at the photographer's right, as far as it goes. |
| C | The miter pair | When the worm's gear reaches the knob's gear it stops: turn the rise knob a little while you push, the teeth slip into mesh and the worm goes the last millimetres. |
| B | Worm plug | Round, with a hole in its top face: hole first, into the bore, under the worm's pin, flush with the bottom face (technique 1). The pin sits in the hole; its end is the thrust bearing that carries the front standard. The plug has a flat notch on one side: turn it to face the camera's centre, in line with the rack's channel. |

Turn the knob: the worm turns with it, freely, with no scraping.

### 5b. The Y plate, up from below

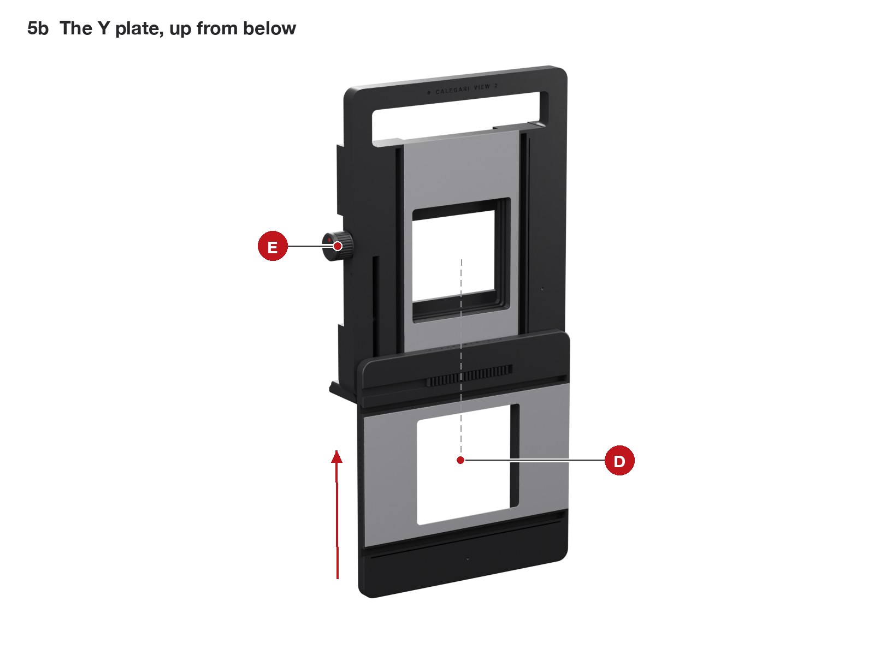
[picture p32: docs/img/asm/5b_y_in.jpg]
5b


| | Part | What to do |
|---|---|---|
| D | Y plate | Hold it under the camera, rear toward the body, its two tongues in the body's two grooves, and slide it up from the bottom of the body. The rise rack runs up the channel on the photographer's right, past the worm plug. |
| E | Rise knob | When the rack reaches the worm the plate stops: turn the knob clockwise while you push gently (technique 4). The worm draws the plate up. Keep turning to the top, where it stops. |

### 5c. The plugs

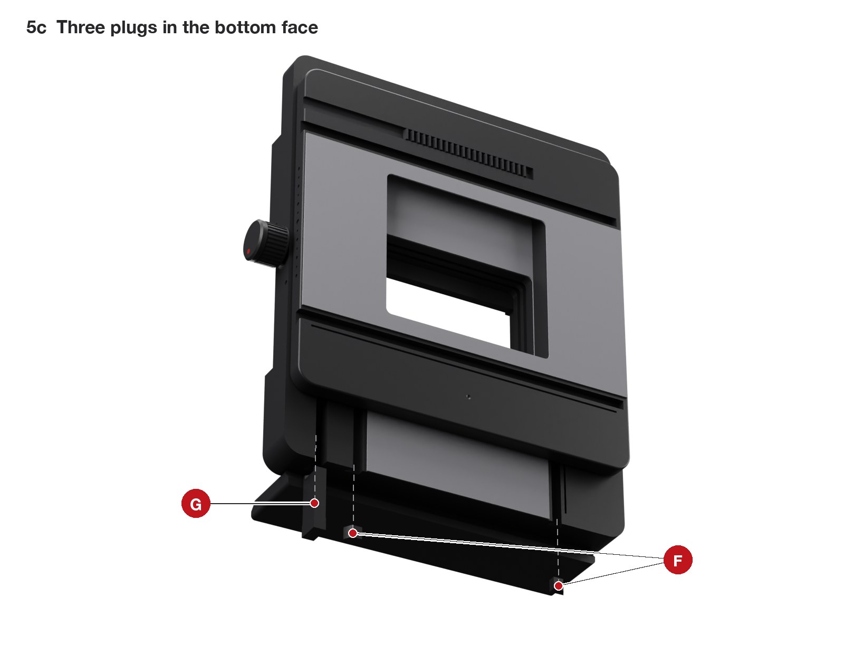
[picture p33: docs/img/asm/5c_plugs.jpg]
5c


| | Part | What to do |
|---|---|---|
| F | Two plugs Y | Press them into the bottom ends of the two grooves, under the body, flush. They stop the fall and keep the plate in. |
| G | Rack plug | Press it into the rack's channel beside the worm plug, flush. It closes the channel below the rack's lowest point. |

Turn the rise knob through the whole travel, 60 mm: about 19 turns, even all the way, one click at zero. Let go anywhere: the plate stays.

---

## 6. The lens panel on the bench

**You need:** the lens panel, the shift pinion.

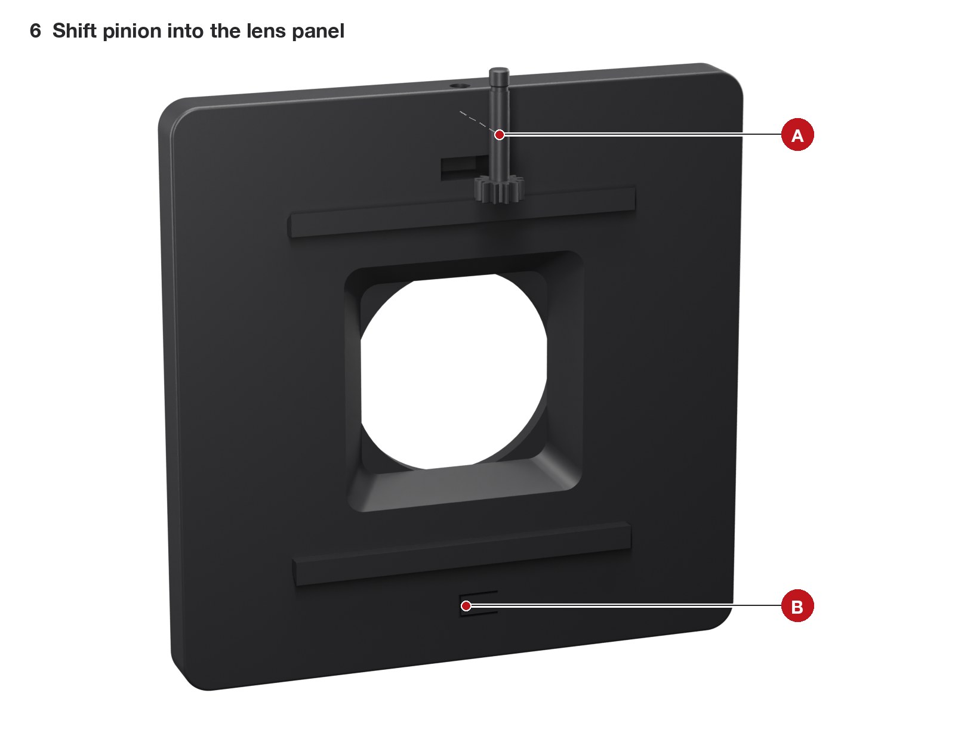
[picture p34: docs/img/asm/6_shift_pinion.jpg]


| | Part | What to do |
|---|---|---|
| A | Shift pinion | From behind, drop it into its pocket at the top of the panel and push the shaft up through the top edge. It stays loose until the panel is in. |
| B | Zero-click spring | As on the Y plate. |

---

## 7. The lens panel onto the Y plate

**You need:** the lens panel with its pinion, two plugs X, a wave washer, the second knob.

### 7a. In from the photographer's right

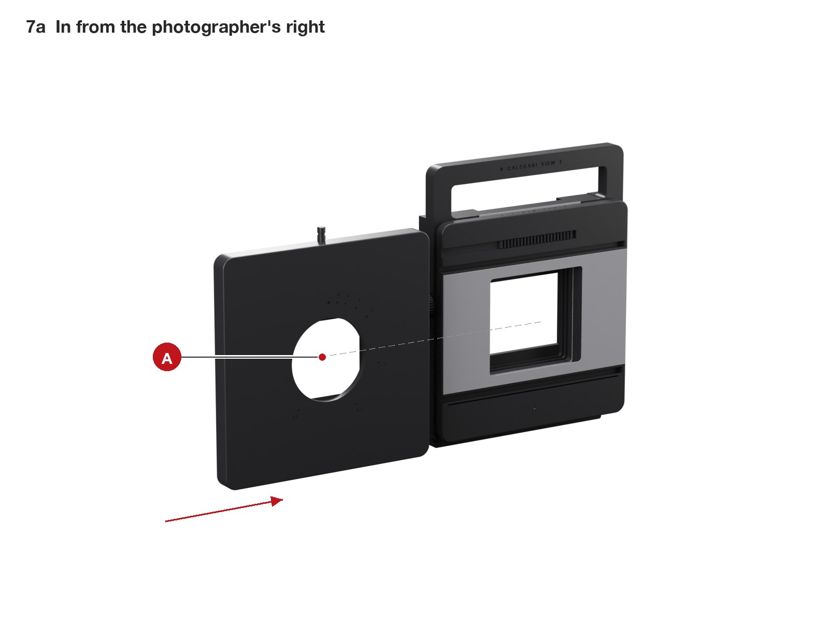
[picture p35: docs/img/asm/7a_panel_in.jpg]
7a


| | Part | What to do |
|---|---|---|
| A | Lens panel | Hold it with the pinion's shaft up and slide it into the Y plate's grooves from the photographer's right. The pinion runs in the channel at the top of the Y plate and meets the shift rack: rock the shaft with your fingers as you push, the teeth engage. Keep going until the panel stops. |

### 7b. The plugs

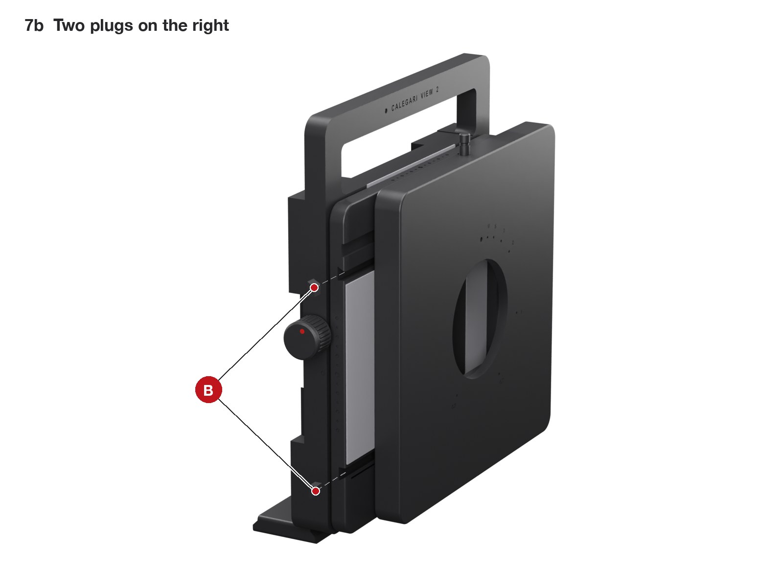
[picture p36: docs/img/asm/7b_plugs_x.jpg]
7b


| | Part | What to do |
|---|---|---|
| B | Two plugs X | With the panel pushed fully to the photographer's left, press them into the right-hand ends of the two grooves, flush. They stop the shift and keep the panel in. |

### 7c. Washer and shift knob

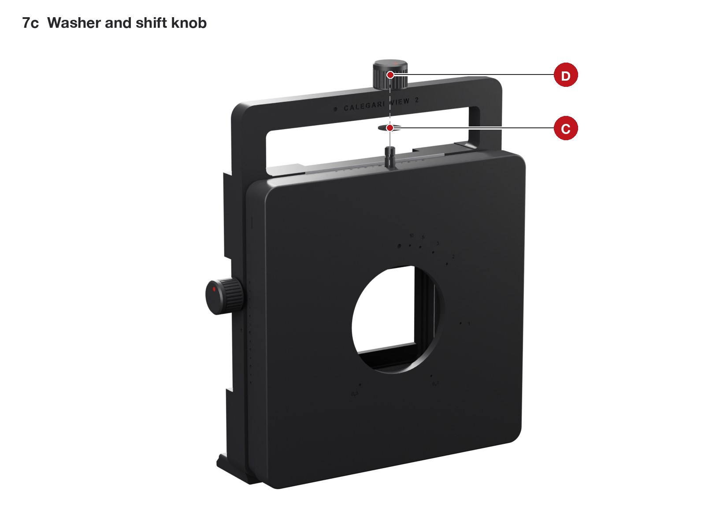
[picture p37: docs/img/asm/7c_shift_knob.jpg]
7c


| | Part | What to do |
|---|---|---|
| C | Wave washer | Over the shaft, on the panel's top edge. |
| D | Knob | Push it onto the shaft, flat to flat, until it clicks (technique 2). It rides with the lens, in the middle of the handle's window at zero: one turn moves the panel 37.7 mm. |

---

## 8. The barrel

**You need:** the helicoid, the lens mount.

### 8a. Helicoid

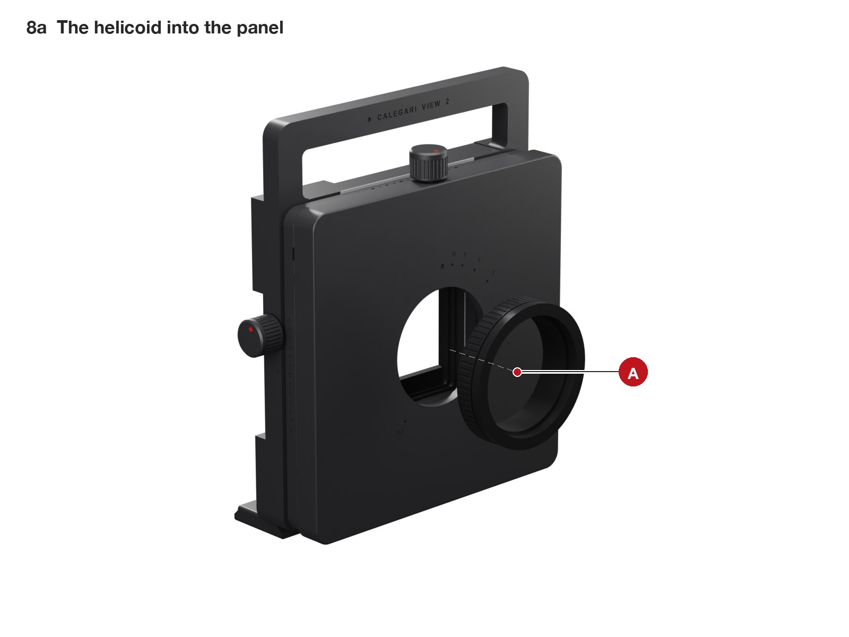
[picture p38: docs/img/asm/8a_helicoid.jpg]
8a


| | Part | What to do |
|---|---|---|
| A | Helicoid | Screw its rear thread into the panel's printed thread, by hand, until it seats. Hold the rear and turn the grip: the front must come out without rotating. |

### 8b. Lens mount

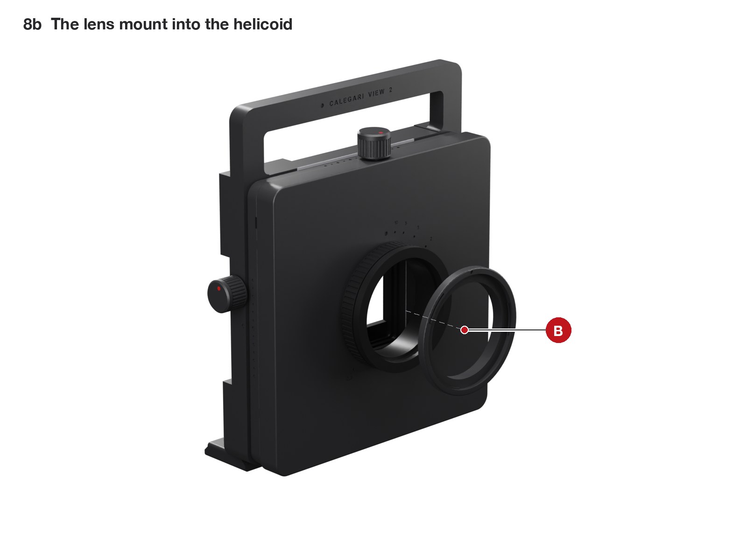
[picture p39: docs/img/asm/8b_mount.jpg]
8b


| | Part | What to do |
|---|---|---|
| B | Lens mount | Screw it into the helicoid's front until it seats. Its red dot ends where it ends: that is fine, the board's lock is what sets the shutter upright. |

---

## 9. The lens

**You need:** the lens board, the lens with its retaining ring.

### 9a. The lens on its board

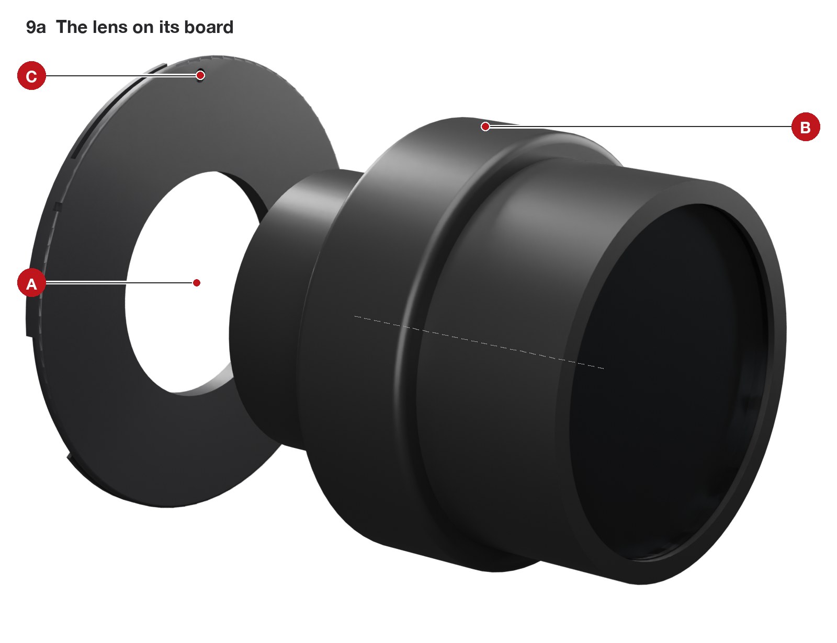
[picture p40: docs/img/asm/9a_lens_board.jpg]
9a


| | Part | What to do |
|---|---|---|
| A | Lens board | |
| B | Lens | Remove the rear cell, put the shutter on the board's front, the rear cell and the retaining ring through from behind. Before you tighten the ring, turn the shutter so that its scales face up and the release lever is where you want it when the board's red dot (C) is at the top. Tighten the ring by hand. |

### 9b. The board into the mount

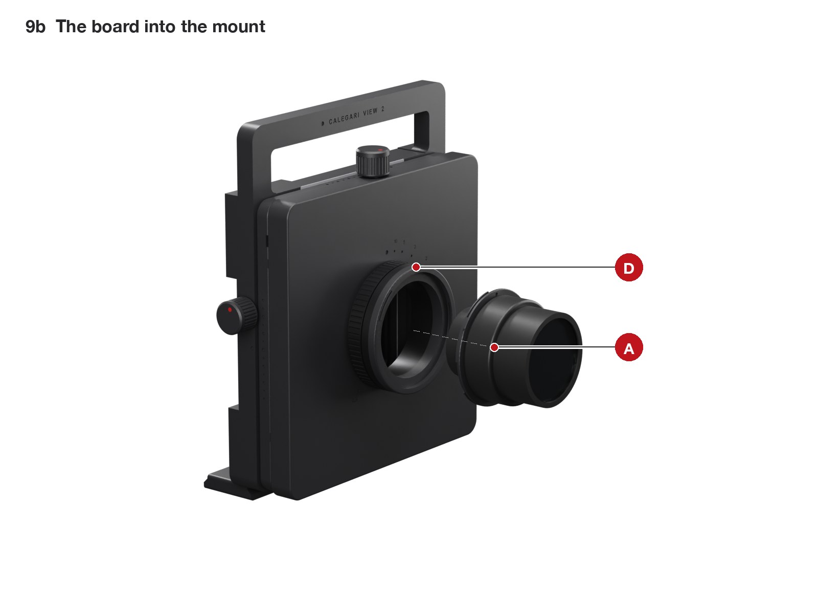
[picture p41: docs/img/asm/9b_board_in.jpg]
9b


| | Part | What to do |
|---|---|---|
| A | Board | Facing the front of the camera, put it in turned about 40 degrees anticlockwise (its red dot left of the mount's red dot, D), push it flat and turn it clockwise until it clicks: the red dots meet, the shutter is upright. To take it out, turn it back firmly. |

---

## 10. The back

**You need:** a Mamiya RB67 back, or the ground glass back.

### 10a. Landscape

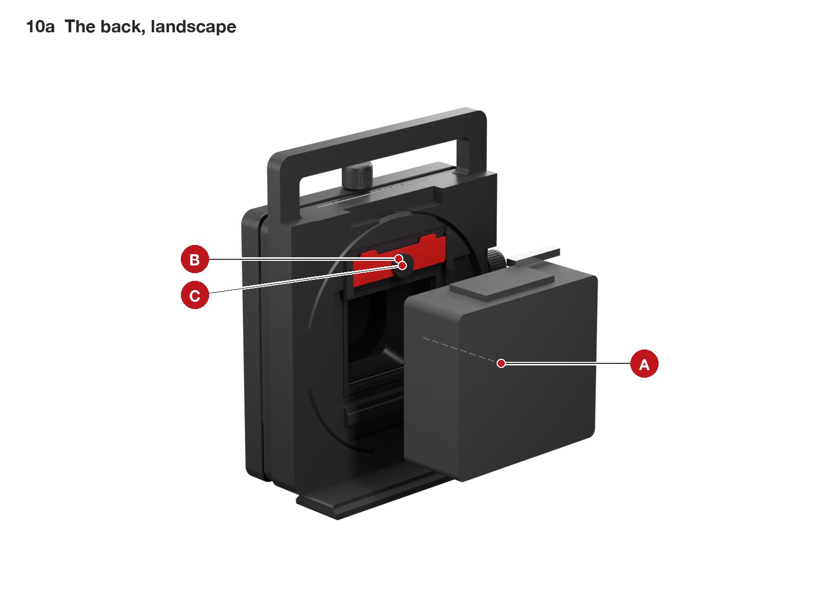
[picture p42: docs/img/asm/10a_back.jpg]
10a


| | Part | What to do |
|---|---|---|
| A | Back | Wheel (C) loose, blade (B) down. Hook the back's lower edge under the rotator's bottom rail, swing it on, push the blade up and tighten the wheel. The dark slide comes out on the photographer's right. |

### 10b. Portrait

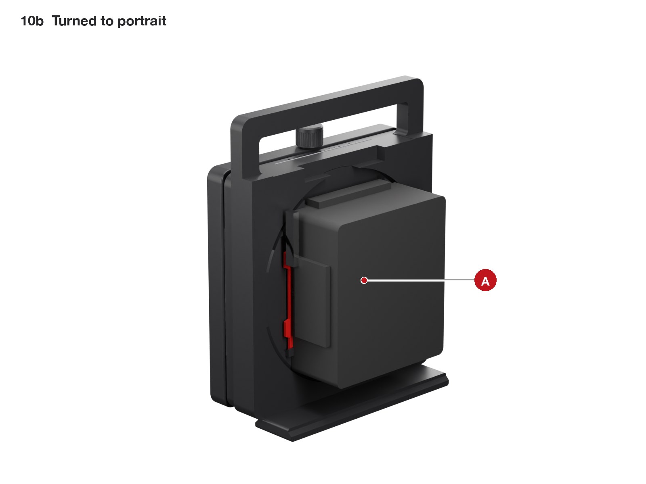
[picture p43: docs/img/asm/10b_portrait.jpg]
10b


Grip the back and turn it a quarter turn anticlockwise, as you look at it from behind, until it clicks: portrait. The dark slide now comes out at the top, under the handle. The camera stays level on the tripod; only the film turns. Turn it back the same way.

---

## 11. Infinity and the index

1. Ground glass on, shutter open at full aperture, something far away in the frame (a kilometre is plenty).
2. Turn the helicoid's grip until the far object is sharp in the loupe. It will be a few degrees before the grip's closed stop: that margin is by design, as on any lens.
3. With a toothpick, put a drop of red acrylic on the grip, exactly under the red dot of the distance scale on the panel.

From now on the index shows the distance on the scale. If infinity is not reached before the stop, or it is more than 30 degrees before it, see [calibration](calibration.md).

## Last checks

| Check | Good |
|---|---|
| Rise knob, the whole travel | even, one click at zero, the plate stays wherever you let go, even with the lens on |
| Shift knob, the whole travel | even, one click at zero, hard stops at 30 mm |
| The back, landscape to portrait | a quarter turn, a click and a stop at each end |
| Light test | [calibration](calibration.md), section 1 |

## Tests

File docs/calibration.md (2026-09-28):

# Calibration

[Back to the project](../README.md)

Most of the calibration happens before the camera exists, on the [test prints](test-prints.md): shrinkage, thread, bayonet, drive and dovetails. What is left is done once the camera is built.

## 1. Light test

1. In a dark room, put the camera on the tripod with the ground glass on and the shutter closed. Throw a dark cloth over the back and your head.
2. With a bright torch, sweep slowly along every joint between the body, the Y plate and the lens panel, from all sides.
3. Repeat with the plates at the four corners of their travel (rise and shift both at 30 mm), and with the back turned to portrait.

The ground glass must stay black. A glow between the plates means the velvet has a gap or lifts at an edge: press it down, or cut a new piece from the template. The narrowest band of velvet between the plates is 6.1 mm at the worst position (`cad/seal_check.py`), so a gap is always a velvet problem, not a geometry one. A glow at the back, around the rotator, means the rotator does not sit flat on its lugs: look for stringing under the lugs and on the ring rib of the recess floor.

## 2. Infinity

The camera is drawn so that, with the reference lens (Super-Angulon 65/8, flange focal distance 70.5 mm), infinity is sharp 0.3 mm before the helicoid's closed stop: about 7 degrees of the grip. The grip turns 22.4 degrees per millimetre of travel.

1. Focus on something far away with a loupe and note how far the grip is from its closed stop, in degrees (a protractor printed on paper and taped to the panel helps).
2. Between 0 and 30 degrees: nothing to do. Paint the index (assembly, step 11).
3. More than 30 degrees: the lens sits too close to the film and you are losing close focus. Print the board again, raised by (degrees / 22.4 - 0.3) mm:

   ```
   python board.py 70.5 --trim 1.2
   ```

4. Not sharp even at the stop: the lens sits too far from the film. Print a board sunk by 0.5 mm (`--trim -0.5`) and repeat until it is.

The board is the only calibration part: a 20 minute print.

## 3. Other lenses

Every lens gets its own board, printed for its flange focal distance (the distance from the shutter's mounting face to the film at infinity; the data sheets call it flange focal distance or Auflagemaß). The board's plateau raises or sinks the lens so that infinity always sits at the same place on the helicoid.

```
python board.py 71.2
```

writes `print/stl/lens_board_71.2.stl`. The camera accepts flange focal distances from 68.0 to 78.5 mm; a board sunk by more than 0.5 mm prints with supports under the rim.

Then check infinity as above. The engraved distance scale is drawn for 65 mm; with a 75 mm lens read it as a rough guide.

## 4. Feel of the movements

| What | If | Do |
|---|---|---|
| A plate is stiff all along | the flexure way is too tight | one light coat of dry PTFE on the tongues (never on the worm); if it is still stiff, `WAY_INTERF` -0.05 and reprint the part with the slotted groove (body for the rise, Y plate for the shift) |
| A plate rocks | the way is loose | `WAY_INTERF` +0.05, same part |
| The rise knob is stiff | the worm is tight in its rack | `WORM_BL` +0.05 and reprint the worm (the rack stays) |
| The rise ever creeps down under a heavy lens | the worm or its rack is lubricated | clean both with alcohol: the dry friction is what locks it (see [design notes](design.md)) |
| A knob is too free or too stiff | the wave washer | reprint its shaft (the shift pinion, or the rise knob's gear) with `KNOB_OFF` -0.1 (stiffer) or +0.1 (freer) |
| A click at zero, or the back's click, is faint or hard | the spring | `DET_T` in `cad/parts.py`: +0.2 harder, -0.2 softer (it sets all five springs) |
| The back turns stiffly or rocks | the rotator on its lugs | the clearance of the lugs' cone, `rot_cone(0.08)` in `cad/parts.py`: +0.05 freer, -0.05 firmer; reprint the body |

## 5. Limits

- **Movements:** 30 mm each way on each axis, mechanical stops. The rise is self-locking at any position; the shift holds by the drag of its knob and ways (the camera stays level, so gravity does not pull it).
- **Back:** landscape and portrait, a click and a stop at each. The camera always sits the same way on the tripod.
- **Corners:** clean at 30 mm on one axis, and at 25 + 25 mm of rise and shift together, at infinity, f/22, in landscape and in portrait (the openings are square, so the frame can turn). Focused at about 0.9 m the combined figure drops to 22 + 22 mm: the helicoid's own rear tube, which the corner rays reach when the lens moves out. Past that, it is the lens's image circle that runs out: a 160 mm circle covers 30 mm on one axis and 25 + 25 combined.
- **Close focus:** about 0.45 m with the 17 to 31 mm helicoid.

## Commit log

2026-09-28 Calegari View 2: a 6x7 view camera printed and assembled without screws
    Rise and shift 30 mm each way on printed flexure dovetails, rack and pinion drives,
    snap-on knobs, a bayonet for round lens boards printed per lens. Parametric model,
    checks, print plates, test plates, illustrated assembly and project page.
    [arca_coupon.stl, body.step, body.stl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]
2026-09-28 Self-locking rise worm and a rotating back
    The rise drive is now a printed worm with a rack moulded into the Y plate as the
    worm's negative: the front standard holds any lens at any height. The back turns
    90 degrees on a round rotator with lugs, printed springs and a stop peg; the side
    leg and the shoes are gone and the camera sits one way on the tripod. Detailed
    assembly guide in 22 illustrated sub-steps, checks in both orientations.
    [body.step, body.stl, drag_washer.step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]
2026-09-28 Rev D: 180 mm block, knobs back, side rise knob through a printed miter pair
    The block grows to 180 mm so the rise drive fits inside the body's right side.
    The knobs of the first revision return: the shift knob is centred in the
    handle's window, the rise knob sits in the middle of the right side face and
    turns the hidden self-locking worm through a 1:1 printed miter pair whose teeth
    end on the back cone. A collar holds the knob's gear in; the worm goes in from
    below before the Y plate, on a notched plug that is its thrust bearing, and a
    second plug closes the rack's channel. Checks: 0 interferences at 11 positions,
    62 fit checks, 6.15 mm velvet seal, optics clean.
    [body.step, body.stl, collar.stl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]
2026-09-28 Rev D: final pass on print notes, weight and filament estimates
    [body.step, drag_washer.step, graflok_blade.step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]
2026-09-29 Print fixes: rack carrier rails up, 45 degree transitions under the miter gears, supports under the lens mount's ring
    [body.step, drag_washer.step, graflok_blade.step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]
